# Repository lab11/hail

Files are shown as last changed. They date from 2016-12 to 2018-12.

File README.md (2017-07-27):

Hail
====

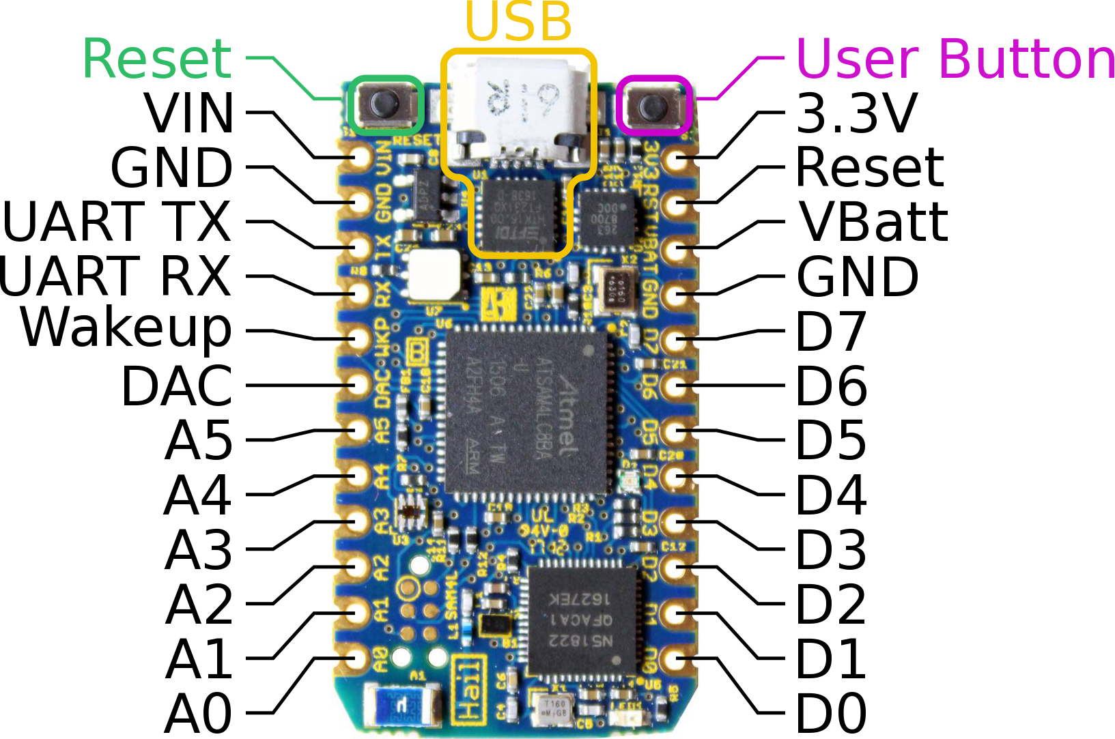
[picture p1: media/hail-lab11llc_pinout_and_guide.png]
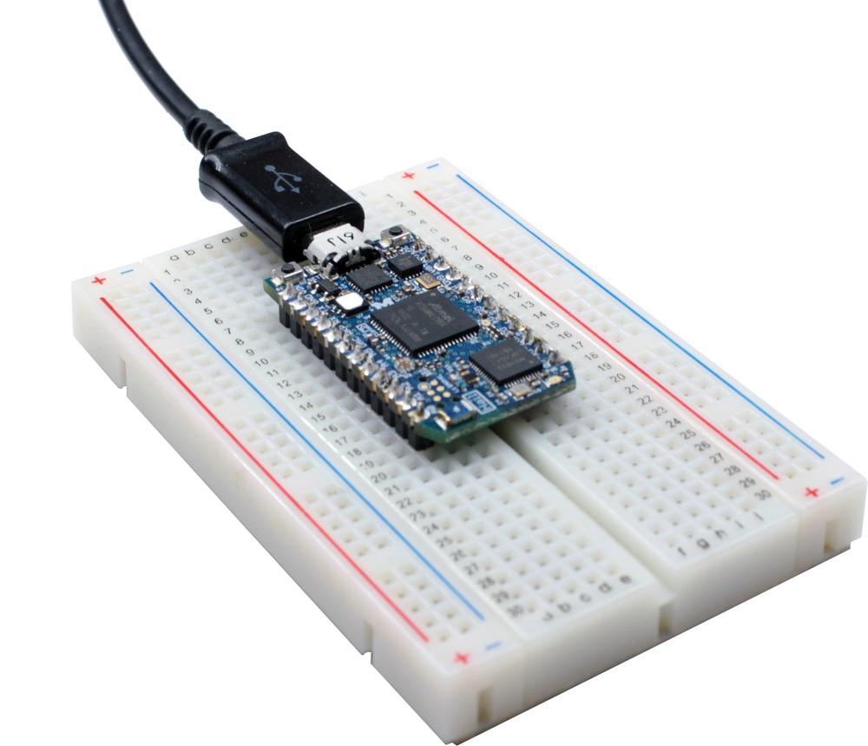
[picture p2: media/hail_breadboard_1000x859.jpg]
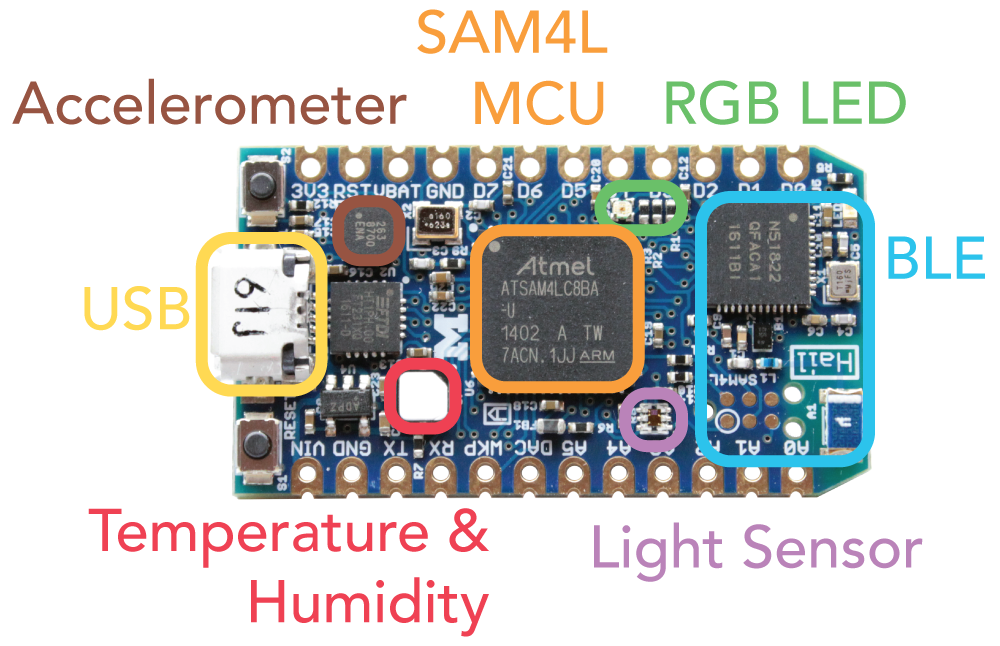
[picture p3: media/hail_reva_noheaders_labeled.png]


Hail is an IoT development module that runs the
[Tock](https://github.com/helena-project/tock) operating system.
Its features:

- [SAM4L](http://www.atmel.com/products/microcontrollers/arm/sam4l.aspx) Cortex-M4
- [nRF51822](https://www.nordicsemi.com/eng/Products/Bluetooth-low-energy/nRF51822) BLE Radio
- [SI7021](https://www.silabs.com/products/sensors/humidity-sensors/Pages/si7013-20-21.aspx) Temperature and Humidity Sensor
- [ISL29035](https://www.intersil.com/en/products/optoelectronics/ambient-light-sensors/light-to-digital-sensors/ISL29035.html) Light Sensor
- [FXOS8700CQ](http://www.nxp.com/products/sensors/6-axis-sensors/digital-sensor-3d-accelerometer-2g-4g-8g-plus-3d-magnetometer:FXOS8700CQ) 6-axis Accelerometer and Magnetometer
- RGB LED
- USB Programming
- Particle [Photon](https://www.particle.io/products/hardware/photon-wifi-dev-kit) Form-Factor and Pinout

**[Buy Now!](https://www.tockos.org/hardware/)**

Hail + Tock
-----------

[TockOS](https://github.com/helena-project/tock/tree/master/boards/hail)
supports Hail. See the instructions there for how to program the Tock kernel
and applications.

Bootloader
----------

Hail supports a software bootloader which allows new code to be flashed
over USB. The bootloader source is in the [bootloader](bootloader) directory.
The [tockloader](https://github.com/helena-project/tockloader) utility
can flash applications using the bootloader.

Commissioning New Hail Boards
-----------------------------

There a couple steps to provision a newly populated Hail board.
See the [commissioning](commissioning) folder for more information.

nRF51822 BLE Radio
------------------

By default, the nRF51822 is commissioned with the
[serialization](https://github.com/helena-project/tock-nrf-serialization)
application which allows softdevice commands to be sent over a UART connection
from the SAM4L.

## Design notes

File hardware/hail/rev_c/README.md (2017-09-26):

Hardware files
==============

Hail was created in [Eagle](http://www.autodesk.com/products/eagle/overview) and the `hail.sch` and
`hail.brd` files are Eagle schematic and board files respectively.

`hail_bom.xlsx` is the Bill of Materials (list of parts). It is also provided
as `.txt` and `.csv` files for convenience.

Rev C changes
-------------

 * Connected ADVREFP to VDDANA.
 * Replace Lab11 logo with text. In practice, it didn't print correctly.

License
-------

<a rel="license" href="http://creativecommons.org/licenses/by-sa/4.0/">
  
</a><br />
This work is licensed under a
<a rel="license" href="http://creativecommons.org/licenses/by-sa/4.0/">Creative Commons Attribution-ShareAlike 4.0 International License</a>.

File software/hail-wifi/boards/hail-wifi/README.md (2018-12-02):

The Hail with Wi-Fi Board
=================

This is the normal Hail board with the Hail-Wifi shield so it can network
over Wi-Fi.

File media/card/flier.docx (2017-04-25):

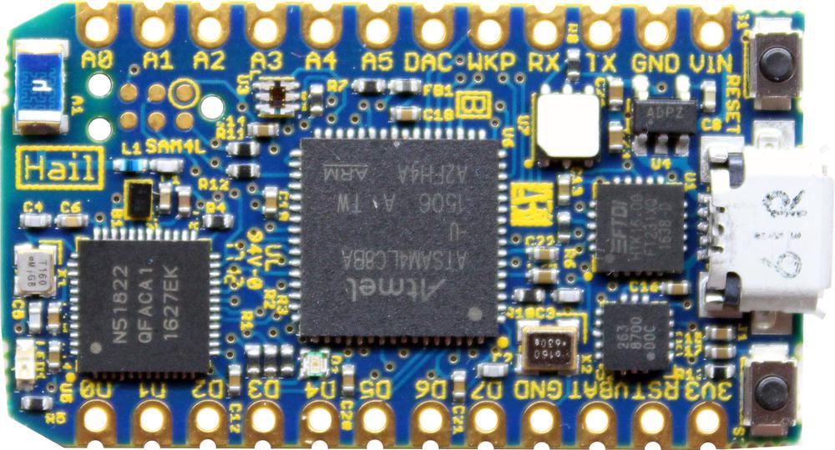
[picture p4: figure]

Hail Development Module

Hails come pre-loaded with a Tock kernel and the hail test app. To see the current readings of the sensors:

$ pip3 install tockloader
$ tockloader listen

For more detailed instructions and tutorials, please visit:

https://github.com/helena-project/tock/tree/master/boards/hail

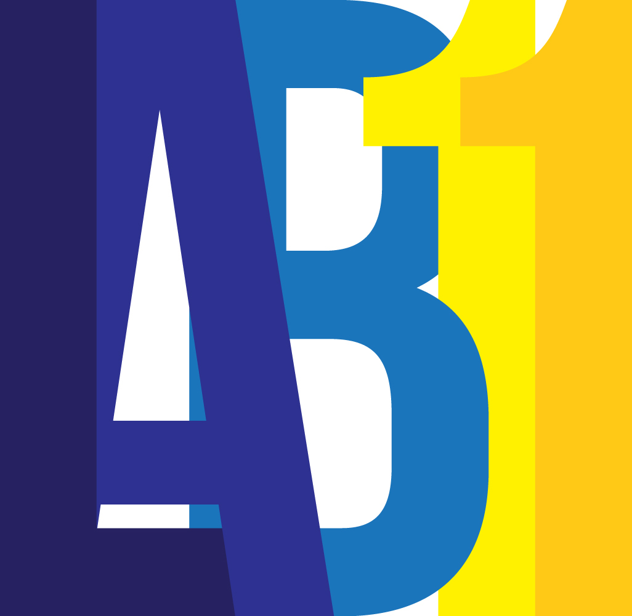
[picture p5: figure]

https://www.tockos.org/

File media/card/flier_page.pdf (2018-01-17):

# Hail Development Module

Hails come preloaded with a Tock kernel and the hail test app.

To see the current readings of the sensors, plug in Hail over USB and:

$ pip3 install tockloader

$ tockloader listen

The blue LED will also blink and pressing the user button turns on the
green LED. For more detailed instructions and tutorials, please visit:

https://www.tockos.org/hardware/hail

# Hail Development Module

Hails come preloaded with a Tock kernel and the hail test app.

To see the current readings of the sensors, plug in Hail over USB and:

$ pip3 install tockloader

$ tockloader listen

The blue LED will also blink and pressing the user button turns on the
green LED. For more detailed instructions and tutorials, please visit:

https://www.tockos.org/hardware/hail

# Hail Development Module

Hails come preloaded with a Tock kernel and the hail test app.

To see the current readings of the sensors, plug in Hail over USB and:

$ pip3 install tockloader

$ tockloader listen

The blue LED will also blink and pressing the user button turns on the
green LED. For more detailed instructions and tutorials, please visit:

https://www.tockos.org/hardware/hail

# Hail Development Module

Hails come preloaded with a Tock kernel and the hail test app.

To see the current readings of the sensors, plug in Hail over USB and:

$ pip3 install tockloader

$ tockloader listen

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

https://www.tockos.org/hardware/hail

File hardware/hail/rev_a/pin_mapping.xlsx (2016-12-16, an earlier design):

Name
Button | PA16
Blue LED | PA13
Green LED | PA14
Red LED | PA15
Particle tx | PA26
Particle rx | PA25
Particle wkp | PA07
Particle dac | PA06
Particle a5 | PB05
Particle a4 | PB04
Particle a3 | PB03
Particle a2 | PB02
Particle a1 | PA05
Particle a0 | PA04
Particle d7 | PB12
Particle d6 | PB11
Particle d5 | PA24
Particle d4 | PA23
Particle d3 | PA21
Particle d2 | PA22
Particle d1 | PB15
Particle d0 | PB14
NRF_IN | PB10
NRF_OUT | PB09
NRF_RTS | PB06
NRF_CTS | PB07
NRF_INT | PB08
NRF_RESET | PA17
Sensors SDA | PB00
Sensors SCL | PB01
Light INT | PA20
ACC INT1 | PA09
ACC INT2 | PA18
FTDI_OUT | PA11
FTDI_IN | PA12
FTDI_RTS | PA08
36

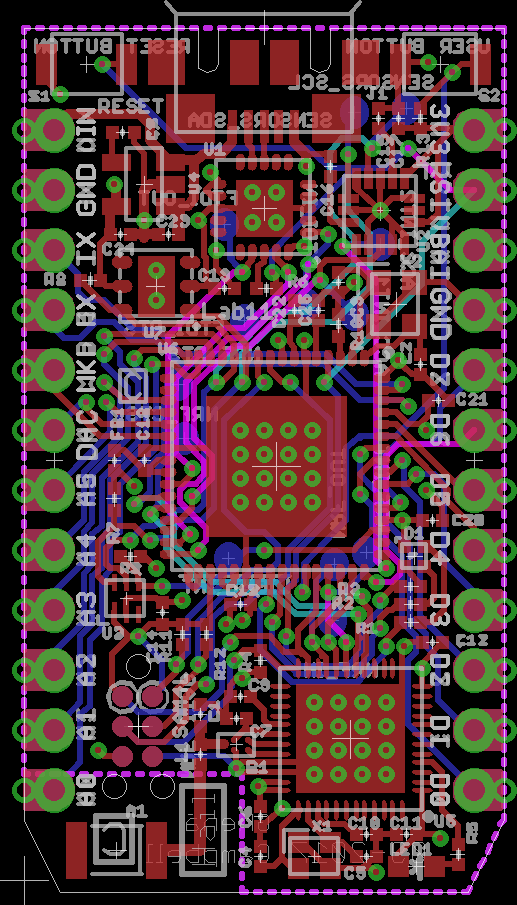
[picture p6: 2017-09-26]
hardware/hail/rev_c/hail_pcb.png

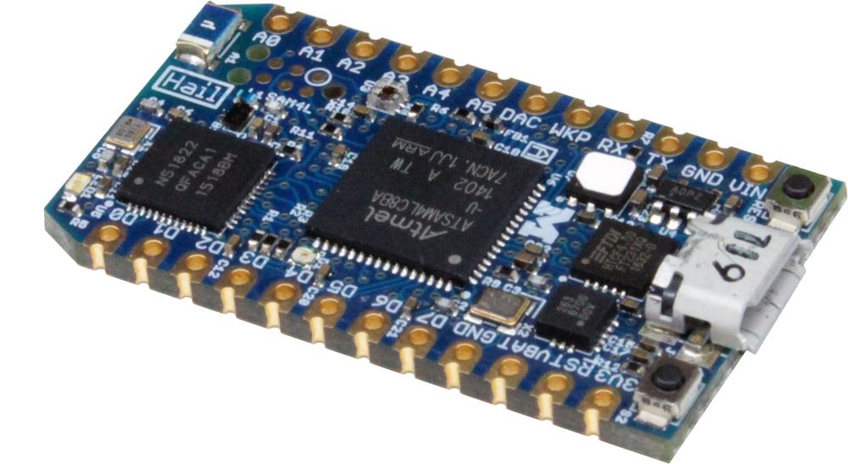
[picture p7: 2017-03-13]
media/hail_reva_isometric_1000x547.jpg

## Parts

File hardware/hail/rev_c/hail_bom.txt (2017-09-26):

# Bill of Materials
# Converted from hail_bom.xlsx
# Generated by bom_to_text.py
#
# # Bill of Materials                                                                                                                                                                                                                                                                                                      
# # Converted from {}                                                                                                                                                                                                                                                                                                      
# # Generated by bom_to_text.py                                                                                                                                                                                                                                                                                            
# #                                                                                                                                                                                                                                                                                                                        
#                                                                                                                                                                                                                                                                                                                          
# Qty                            Value                           Device                          Package                          Parts                                                            Description                                                     MPN              DIGIKEY               MOUSER           RICHARDSON_RFPD
1                                FRACTUS-2.4GHZ-FR05-S1-N-0-110  FRACTUS-2.4GHZ-FR05-S1-N-0-110  FRACTUS-ANTENNA-FR05-S1-N-0-110  A1                                                               Fractus Micro Reach Xtend                                                                                               FR05-S1-N-0110B
1                                BAL-NRF01D3                     BAL-NRF01D3                     BAL-NRF01D3                      B1                                                               50 ohm nominal input / conjugate match balun to nRF51422-QFAA,                   497-13637-1-ND        511-BAL-NRF01D3  
1                                1.5pF                           CAPACITOR0402_CAP               0402_CAP                         C1                                                               0402 Capacitor                                                                   490-6212-1-ND                          
2                                8pF                             CAPACITOR0402_CAP               0402_CAP                         C2, C3                                                           0402 Capacitor                                                                   490-8230-1-ND                          
2                                12pF                            CAPACITOR0402_CAP               0402_CAP                         C4, C5                                                           0402 Capacitor                                                                   490-6197-1-ND                          
1                                1nF                             CAPACITOR0402_CAP               0402_CAP                         C6                                                               0402 Capacitor                                                                   490-1303-1-ND                          
1                                2.2nF                           CAPACITOR0402_CAP               0402_CAP                         C7                                                               0402 Capacitor                                                                   490-5419-1-ND                          
1                                10nF                            CAPACITOR0402_CAP               0402_CAP                         C8                                                               0402 Capacitor                                                                   490-7763-1-ND                          
1                                47nF                            CAPACITOR0402_CAP               0402_CAP                         C9                                                               0402 Capacitor                                                                   445-1264-1-ND                          
13                               100nF                           CAPACITOR0402_CAP               0402_CAP                         C10, C11, C12, C13, C14, C15, C16, C17, C18, C19, C20, C21, C22  0402 Capacitor                                                                   490-10777-1-ND                         
3                                4.7uF                           CAPACITOR0402_CAP               0402_CAP                         C23, C24, C25                                                    0402 Capacitor                                                                   490-13252-1-ND                         
1                                SML-LX0404SIUPGUSB              SML-LX0404SIUPGUSB              1MM_SQ_4PAD                      D1                                                               1mm^2 RGB LED                                                                    67-2125-1-ND                           
1                                1.5k                            FERRITE_BEAD0402                0402_CAP                         FB1                                                                                                                                               1276-6395-1-ND                         
1                                MICRO_USB_B_HIROSE_ZX62R-B-5P   MICRO_USB_B_HIROSE_ZX62R-B-5P   USB_MICRO_B-HIROSE-ZX62R-B-5P    J1                                                               USB Micro B Connector                                                            H125274CT-ND                           
1                                M12PTH-CST-L                    M12PTH-CST-L                    1X12-CASTELLATED                 J2                                                               Header 12                                                                        S1011E-12-ND                           
1                                M12PTH-CST-R                    M12PTH-CST-R                    1X12-CASTELLATED                 J3                                                               Header 12                                                                        S1011E-12-ND                           
1                                6.8nH                           INDUCTOR0402                    0402_CAP                         L1                                                               A very specific inductor                                                         490-6840-1-ND                          
1                                LED0603                         LED0603                         LED-0603                         LED1                                                             LED                                                                              160-1837-6-ND                          
6                                1k                              RESISTOR0402_RES                0402_RES                         R1, R2, R3, R4, R5, R6                                           Resistor                                                                         1276-3430-1-ND                         
4                                10k                             RESISTOR0402_RES                0402_RES                         R7, R8, R9, R10                                                  Resistor                                                                         1276-3431-1-ND                         
3                                100k                            RESISTOR0402_RES                0402_RES                         R11, R12, R13                                                    Resistor                                                                         1276-3432-1-ND                         
2                                B3U-1000P                       B3U-1000P                       B3U-1000P                        S1, S2                                                           Switch                                                                           SW1020CT-ND                            
1                                FT231XQ                         FT231XQ                         QFN-20-4MM                       U1                                                               USB Bridge, USB to UART USB 2.0 UART Interface                  FT231XQ-R        768-1128-1-ND                          
1                                FXOS8700CQ                      FXOS8700CQ                      QFN-16-3MM                       U2                                                               Accelerometer, Magnetometer, 3 Axis Sensor, I2C/SPI             FXOS8700CQR1     FXOS8700CQR1CT-ND                      
1                                ISL29035                        ISL29035                        ODFN-6-1.5MMX1.6MM               U3                                                               Optical Sensor Ambient 550nm I2C                                ISL29035IROZ-T7  ISL29035IROZ-T7CT-ND                   
1                                MAX8887EZK33+T                  MAX8887EZK33+T                  SOT-23-5                         U4                                                               IC REG LDO 3.3V 0.3A TSOT23-5                                                    MAX8887EZK33+TCT-ND                    
1                                NRF51822QF                      NRF51822QF                      QFN-48-6MM                       U5                                                               Multiprotocol Bluetooth 4.0 low energy/2.4 GHz RF SoC                            1490-1049-1-ND                         
1                                SAM4LC8BA                       SAM4LC8BA                       QFN-64-9MM                       U6                                                               SAM4L Microcontroller. 64QFN Package. 512 Flash.                                 ATSAM4LC8BA-MURCT-ND                   
1                                SI7021                          SI7021                          DFN-6/3MM                        U7                                                               IC TEMP SENSOR RH 2% DFN                                                         336-3141-ND                            
1                                16MHz                           TXC-8Y                          TXC-8Y                           X1                                                               2mmx1.6mm SMD Crystal                                                            887-2003-1-ND                          
1                                16MHz                           FH1600015                       FHXXX                            X2                                                               Pericom Type FH 16 MHz 2.5 x 2.0 mm                                              FH1600015CT-ND

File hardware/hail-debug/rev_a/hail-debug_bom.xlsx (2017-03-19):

Qty | Value | Device | Package | Parts | Description | DIGIKEY | MOUSER | NEWARK
24 | MILLMAX_0908-X-15-20-75-14-11-0 | MILLMAX_0908-X-15-20-75-14-11-0 | POGO_0908-X-15-20-75-14-11-0 | J1, J2, J3, J4, J5, J6, J7, J8, J9, J10, J11, J12, J13, J14, J15, J16, J17, J18, J19, J20, J21, J22, J23, J24 |  | ED90384-ND
19 | MILLMAX_0985-X-15-20-71-14-11-0 | MILLMAX_0985-X-15-20-71-14-11-0 | POGO_0985-X-15-20-71-14-11-0 | J25, J26, J27, J28, J29, J30, J31, J32, J33, J34, J35, J36, J37, J38, J39, J40, J41, J42, J43 |  | ED1122-ND
2 |  | PINHD-2X12 | 2X12 | J44, J45 | PIN HEADER | S2011EC-12-ND
1 |  | PINHD-2X14 | 2X14 | J46 | PIN HEADER | S2011EC-14-ND
2 | SCREW-TERMINAL_7_0.100 | SCREW-TERMINAL_7_0.100 | CONN_BLOCK_7 | J47, J48 | 7x 0.100 in screw terminal block | 277-1278-ND | 651-1725708 | 14X4980
2 | SCREW_TERMINAL_12_0.100 | SCREW_TERMINAL_12_0.100 | CONN_BLOCK_12 | J49, J50 |  | 277-1283-ND
1 | PTS645SM43SMTR92 | PTS645SM43SMTR92 | PTS645 | S1 | Tactile Switch SPST-NO Top Actuated Surface Mount | CKN9112CT-ND

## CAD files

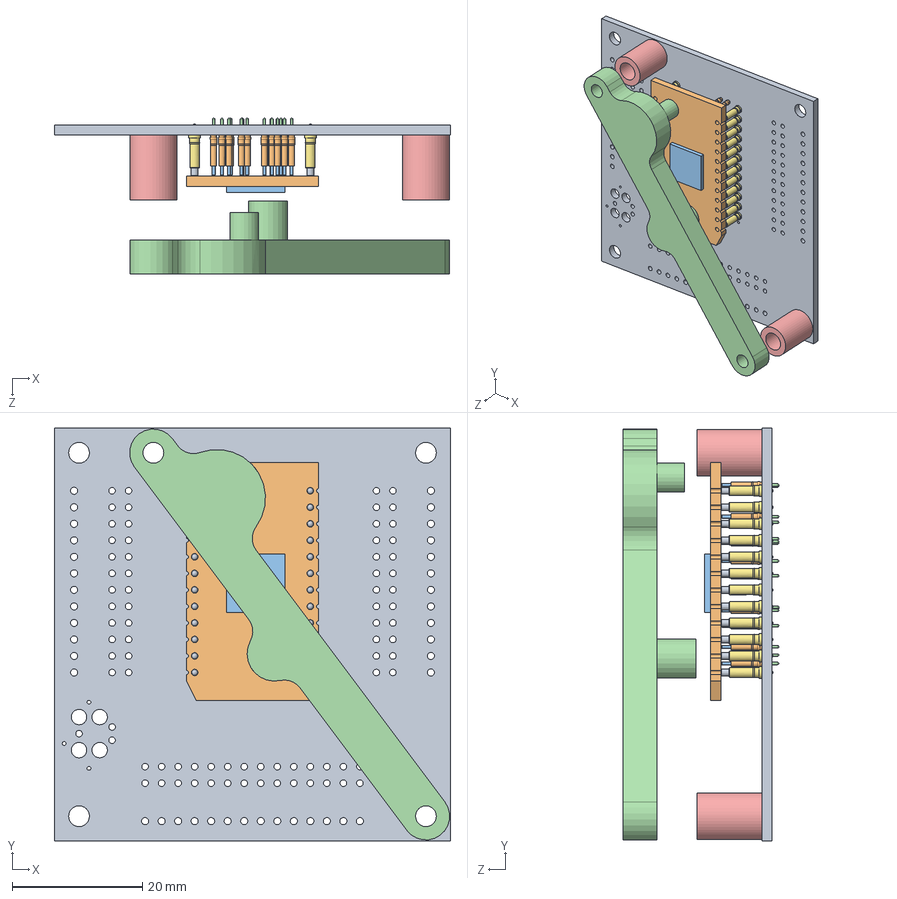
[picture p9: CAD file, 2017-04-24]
3d/hail-debug/hail-debug.SLDASM
61.0 x 63.5 x 23.9 mm
haildebug
mill-max-0985-0-15-20-71-14-11-0_9350-0 x 19
mill-max-0985-0-15-20-71-14-11-0_9315-0 x 19
mill-max-0985-0-15-20-71-14-11-0_9385-X x 19
mill-max-0985-0-15-20-71-14-11-0_SPRING x 19
mill-max-0908-0-15-20-75-14-11-0_0963-0 x 24
mill-max-0908-0-15-20-75-14-11-0_0954-0 x 24
mill-max-0908-0-15-20-75-14-11-0_SPRING x 24
mill-max-0908-0-15-20-75-14-11-0_0918-X x 24
hail
sam4l
holder_bracket_long
holder_bracket_post x 2

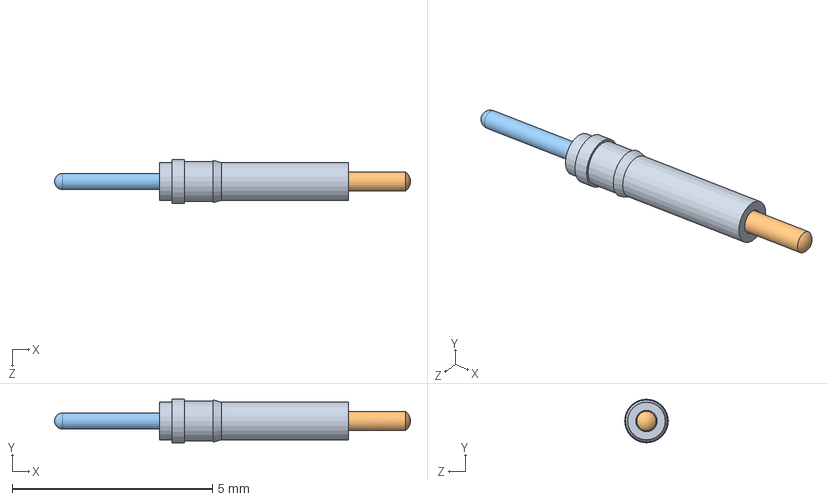
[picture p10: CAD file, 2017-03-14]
3d/mill-max-0985-0-15-20-71-14-11-0/mill-max-0985-0-15-20-71-14-11-0.sldasm
8.89 x 1.09 x 1.09 mm
mill-max-0985-0-15-20-71-14-11-0_9350-0
mill-max-0985-0-15-20-71-14-11-0_9315-0
mill-max-0985-0-15-20-71-14-11-0_9385-X
mill-max-0985-0-15-20-71-14-11-0_SPRING

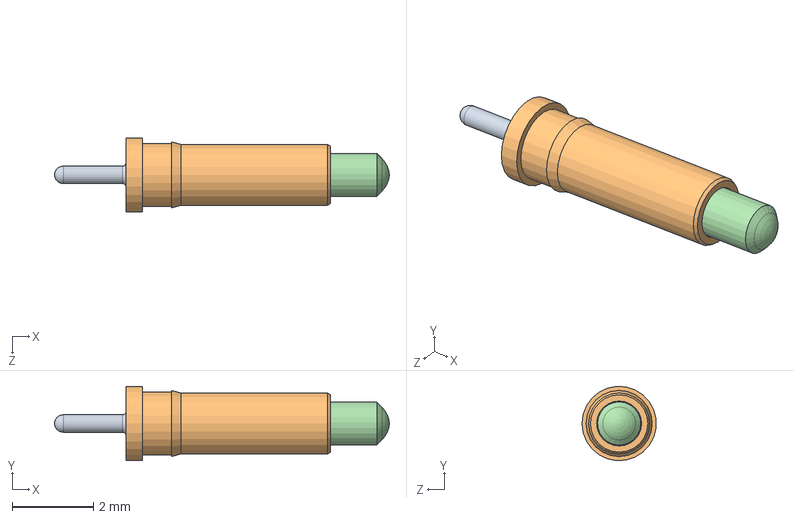
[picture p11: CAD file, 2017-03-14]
3d/mill-max-0908-0-15-20-75-14-11-0/mill-max-0908-0-15-20-75-14-11-0.sldasm
8.23 x 1.83 x 1.82 mm
mill-max-0908-0-15-20-75-14-11-0_0963-0
mill-max-0908-0-15-20-75-14-11-0_0954-0
mill-max-0908-0-15-20-75-14-11-0_SPRING
mill-max-0908-0-15-20-75-14-11-0_0918-X

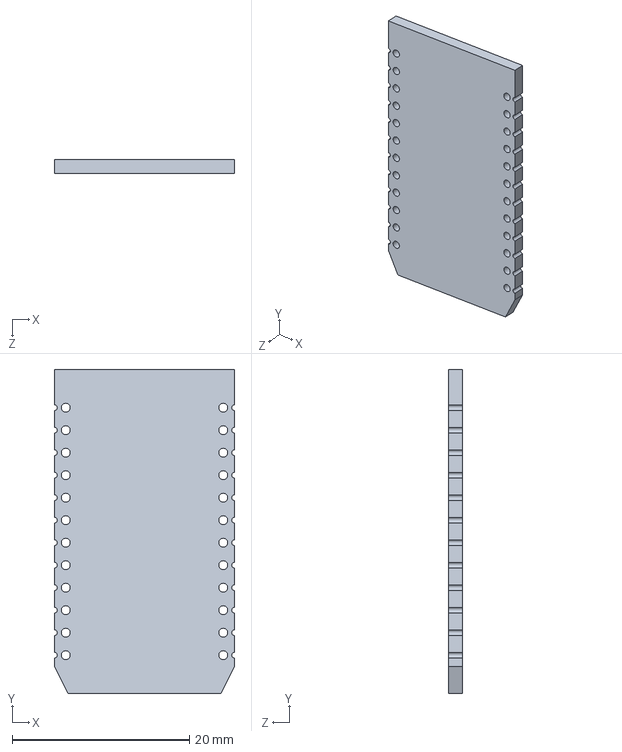
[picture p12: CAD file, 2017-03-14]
3d/hail-debug/hail.SLDASM
20.3 x 36.6 x 1.58 mm

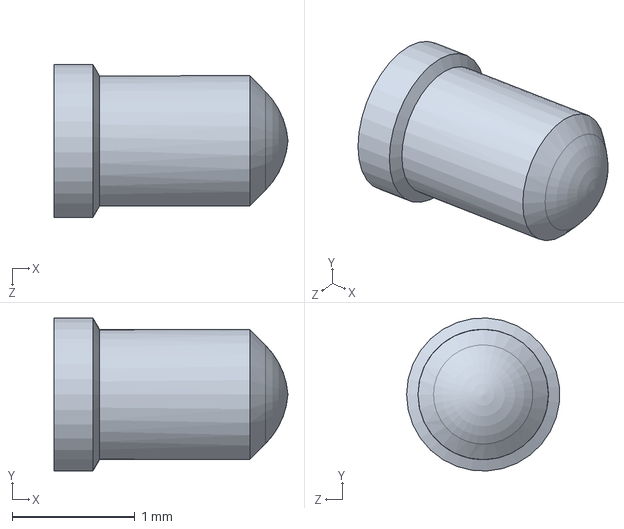
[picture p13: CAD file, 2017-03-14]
3d/mill-max-0908-0-15-20-75-14-11-0/mill-max-0908-0-15-20-75-14-11-0_0918-X.sldprt
1.90 x 1.25 x 1.24 mm

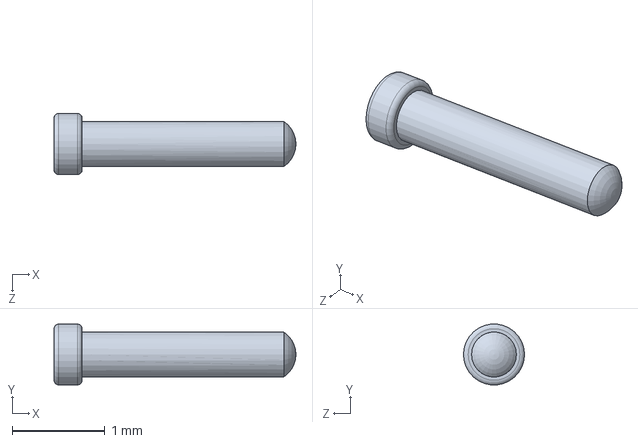
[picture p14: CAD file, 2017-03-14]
3d/mill-max-0985-0-15-20-71-14-11-0/mill-max-0985-0-15-20-71-14-11-0_9315-0.sldprt
2.62 x 0.657 x 0.66 mm

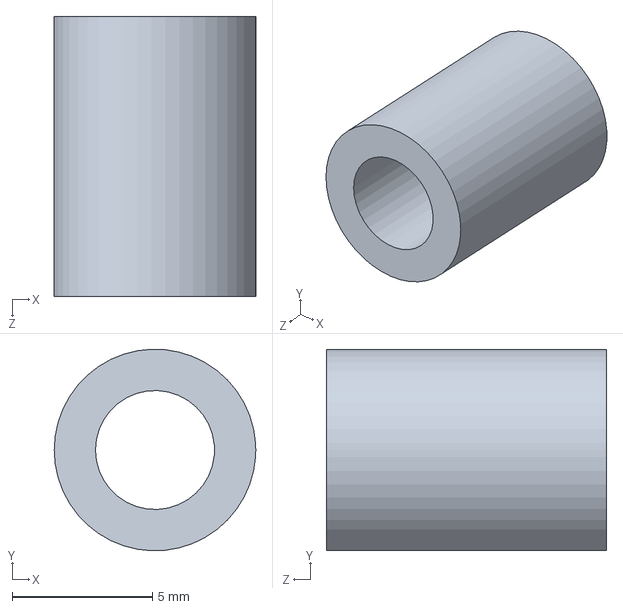
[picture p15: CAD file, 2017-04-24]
3d/hail-debug/holder_bracket_post.SLDPRT
7.20 x 7.20 x 10.0 mm

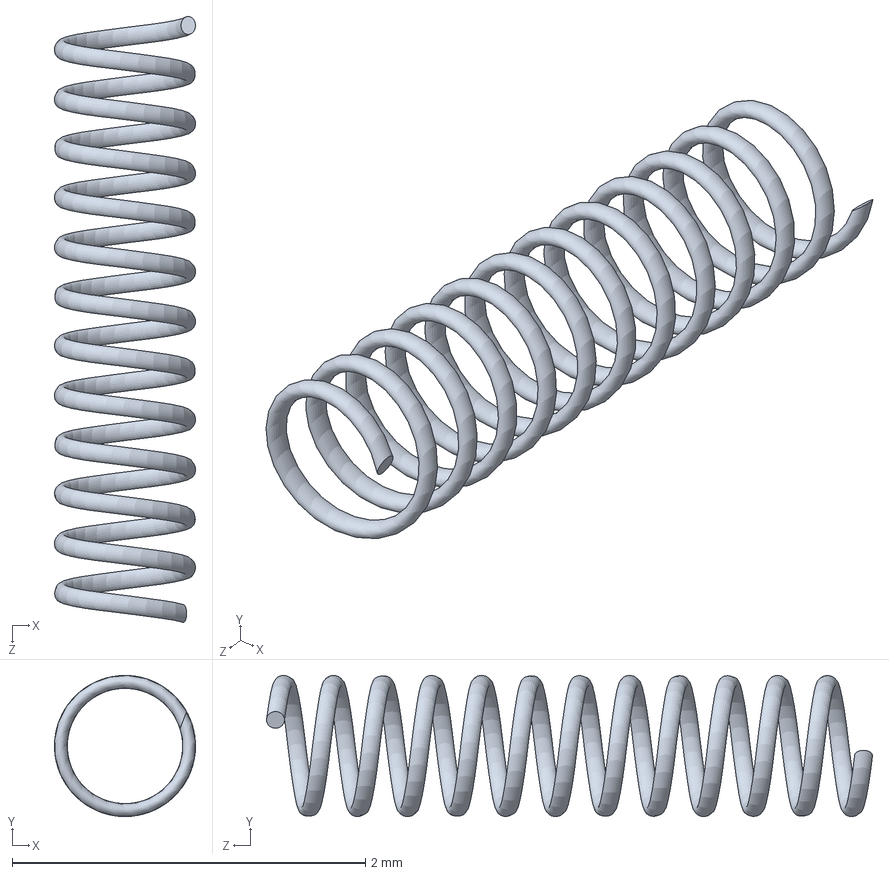
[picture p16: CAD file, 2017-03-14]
3d/mill-max-0908-0-15-20-75-14-11-0/mill-max-0908-0-15-20-75-14-11-0_SPRING.sldprt
0.799 x 0.799 x 3.43 mm

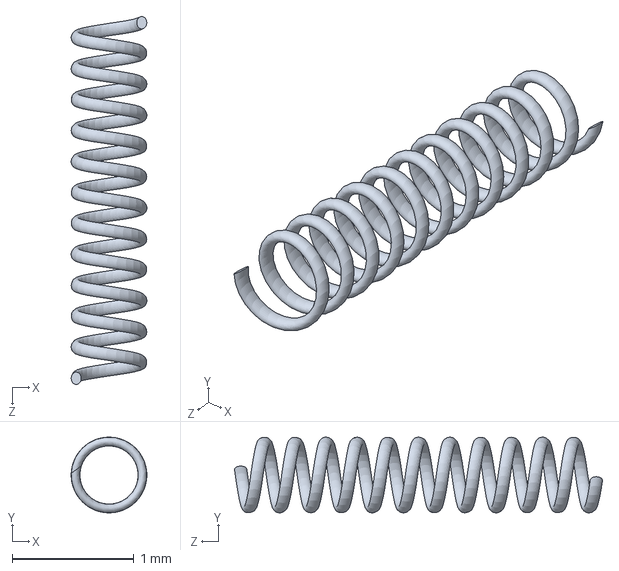
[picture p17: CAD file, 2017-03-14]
3d/mill-max-0985-0-15-20-71-14-11-0/mill-max-0985-0-15-20-71-14-11-0_SPRING.sldprt
0.622 x 0.622 x 3.02 mm

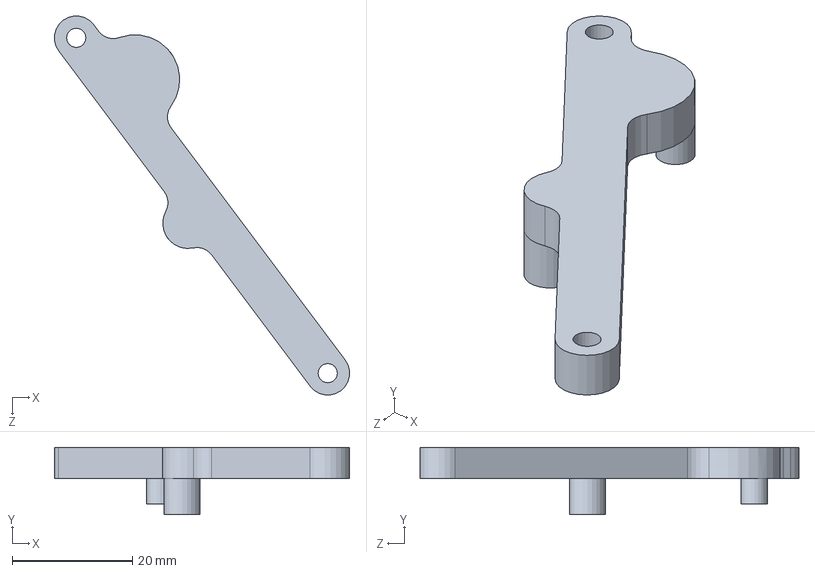
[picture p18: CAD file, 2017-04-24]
3d/hail-debug/holder_bracket_long.SLDPRT
49.2 x 11.2 x 63.1 mm

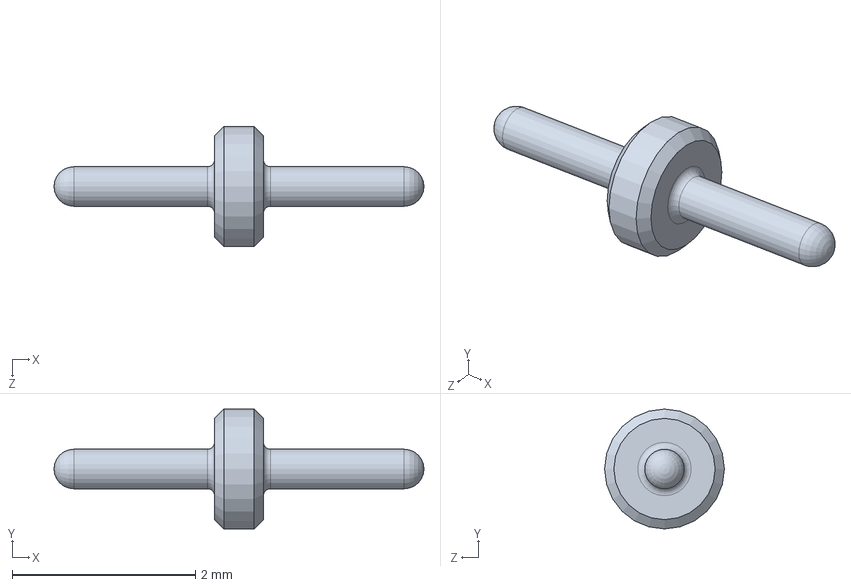
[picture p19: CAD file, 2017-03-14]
3d/mill-max-0908-0-15-20-75-14-11-0/mill-max-0908-0-15-20-75-14-11-0_0963-0.sldprt
4.04 x 1.31 x 1.31 mm

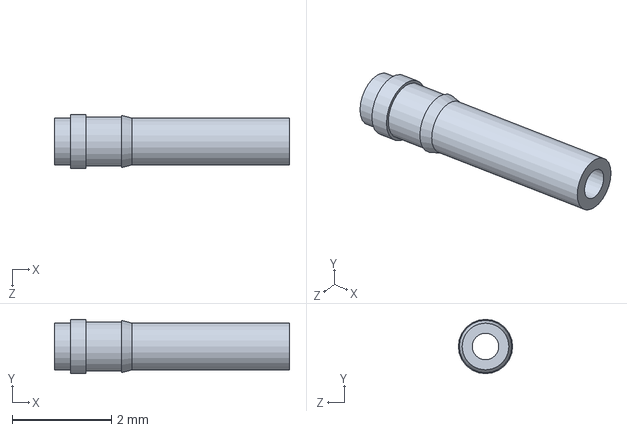
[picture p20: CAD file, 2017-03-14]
3d/mill-max-0985-0-15-20-71-14-11-0/mill-max-0985-0-15-20-71-14-11-0_9350-0.sldprt
4.72 x 1.09 x 1.09 mm

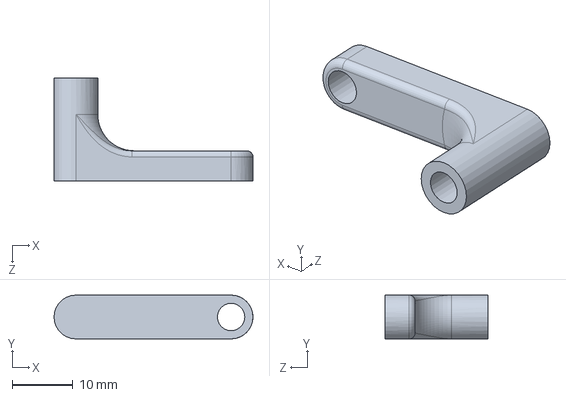
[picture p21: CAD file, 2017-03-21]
3d/hail-debug/holder_bracket.SLDPRT
32.7 x 7.20 x 17.0 mm

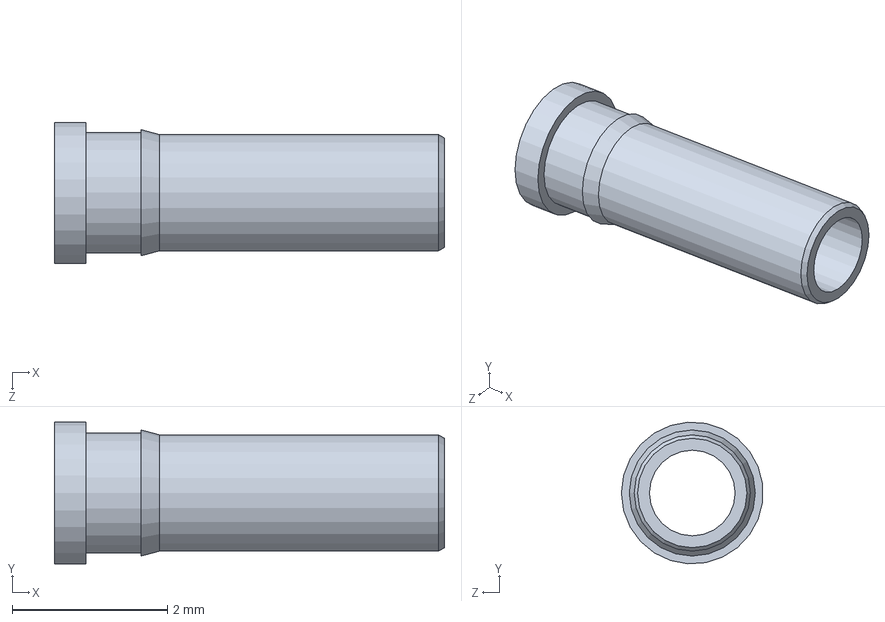
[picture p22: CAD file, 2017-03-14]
3d/mill-max-0908-0-15-20-75-14-11-0/mill-max-0908-0-15-20-75-14-11-0_0954-0.sldprt
5.03 x 1.83 x 1.82 mm

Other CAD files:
3d/hail-debug/sam4l.SLDPRT
3d/mill-max-0985-0-15-20-71-14-11-0/mill-max-0985-0-15-20-71-14-11-0_9385-X.sldprt

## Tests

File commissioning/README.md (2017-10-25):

Commissioning
=============

This folder contains resources for setting up new Hail boards.

Commissioning Overview
----------------------

The commissioning process covers a few things:

1. Set the FTDI device name and serial number.
2. Flashes the boatloader on to the SAM4L.
3. Sets the `board` and `id` attributes in the flash of the SAM4L.
4. Flashes the `hail` TockOS kernel on the SAM4L.
5. Flashes the "hail" app on the SAM4L.
6. Flashes the serialization code on the nRF51822 and programs the ID.

Initial software installation
-----------------------------

### Pre-Requisites:

  - You need the `libftdi-dev` package (or equivalent).
  - [JLinkExe](https://www.segger.com/downloads/jlink#J-LinkSoftwareAndDocumentationPack)

-------------

To initialize a Hail board:

 * Connect USB to the board
 * Connect a JTAG programmer to the SAM4L
 * Run `./commission_new_hail.sh c098e513XXXX` where the `XXXX` should be
   replaced with a unique device ID
 * Connect a JTAG programmer to the nRF51822
 * Hit `any key` to continue the script

Be sure to label the board with a sticker so that the user knows what the
device's BLE address is.

`ftx_prog`
----------

The `ftx_prog` executable comes from here:
https://github.com/richardeoin/ftx-prog.
It was built for linux amd64, so if the executable doesn't work for you,
you will have to recompile it for your platform.

Testing
-------

1. Connect Hail to USB
2. Run `tockloader listen` and verify that code is running
3. Press the reset button and verify that code restarts
4. Press the User button and verify that the green led activates
5. Hold the Hail in your hand and verify that the light and acceleration measurements change
6. Verify that BLE is transmitting with the name of `Hail` and that the address matches the sticker

For BLE testing, I recommend running
`sudo stdbuf -oL hcitool lescan --duplicates | grep Hail` in the background.

Troubleshooting
---------------

### Permissions

    ftdi_usb_open() failed for 0403:6015: inappropriate permissions on device!

You need to add a udev rule for FTDI devices:

    sudo cp udev/99-ftdi.rules /etc/udev/rules.d/

Then unplug and replug attached FTDI devices.

### Device not found

    ftdi_usb_open() failed for 0403:6015: device not found

This seems to occasionally happen. Just run the script again.

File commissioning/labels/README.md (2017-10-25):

Hail Labels
===========

To generate labels:

    ./labels.py [michgan|lab11llc] <id> <count>

For example:

    ./labels.py michigan 005c 100

To make 100 labels with the block "M" on them starting at address
`C0:98:E5:13:00:5C`.

Warning
-------

You may have to manually install `svgutils` in order to get everything working.
Their pip package is way out of date. [Go here](https://github.com/btel/svg_utils).

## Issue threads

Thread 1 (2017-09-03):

ADVREFP needs to be tied to VDDANA

brghena, 2017-09-03:
ADVREFP should be connected to VDDANA. This can be done on existing boards with a small solder jumper (and has been done for boards shipped to macrofab). We should fix this for future revisions though. Mentioning as an issue so we don't forget about it.

Closed 2017-09-26.

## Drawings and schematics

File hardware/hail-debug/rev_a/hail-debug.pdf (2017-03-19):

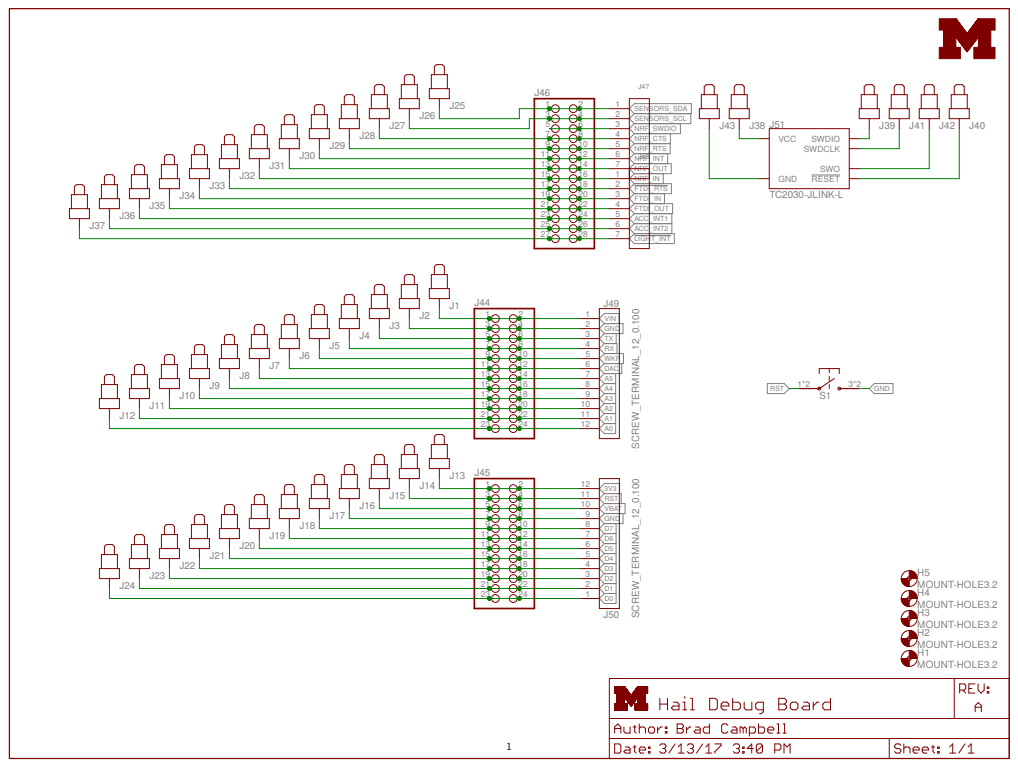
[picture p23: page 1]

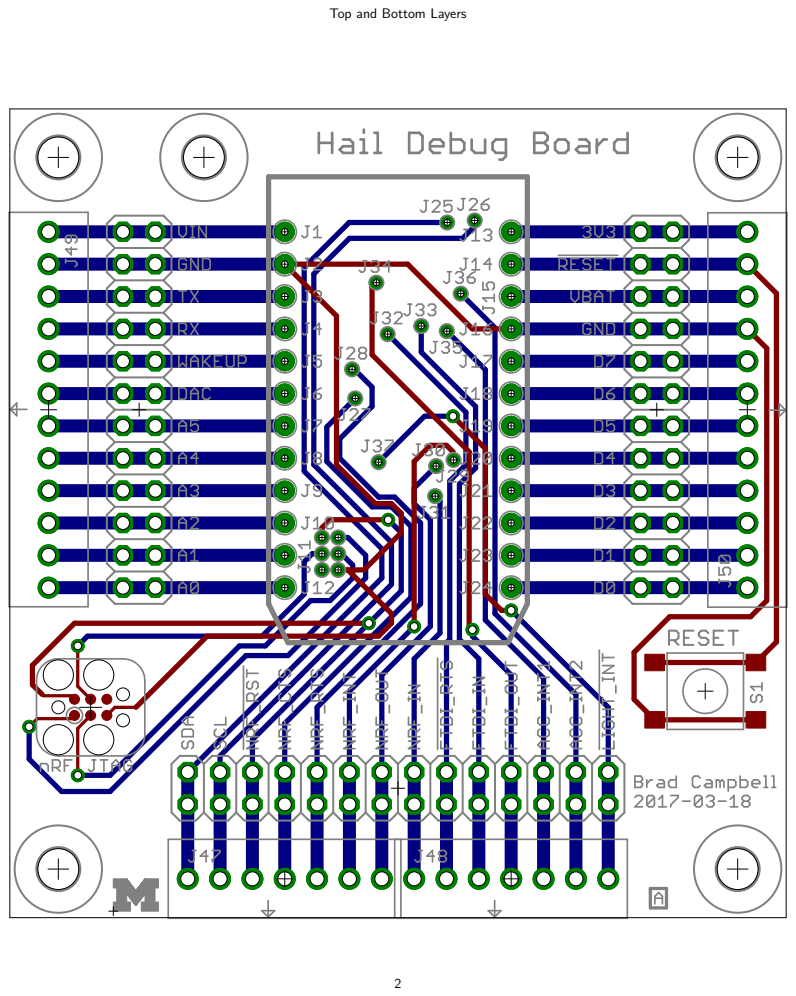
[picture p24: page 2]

Top and Bottom Layers

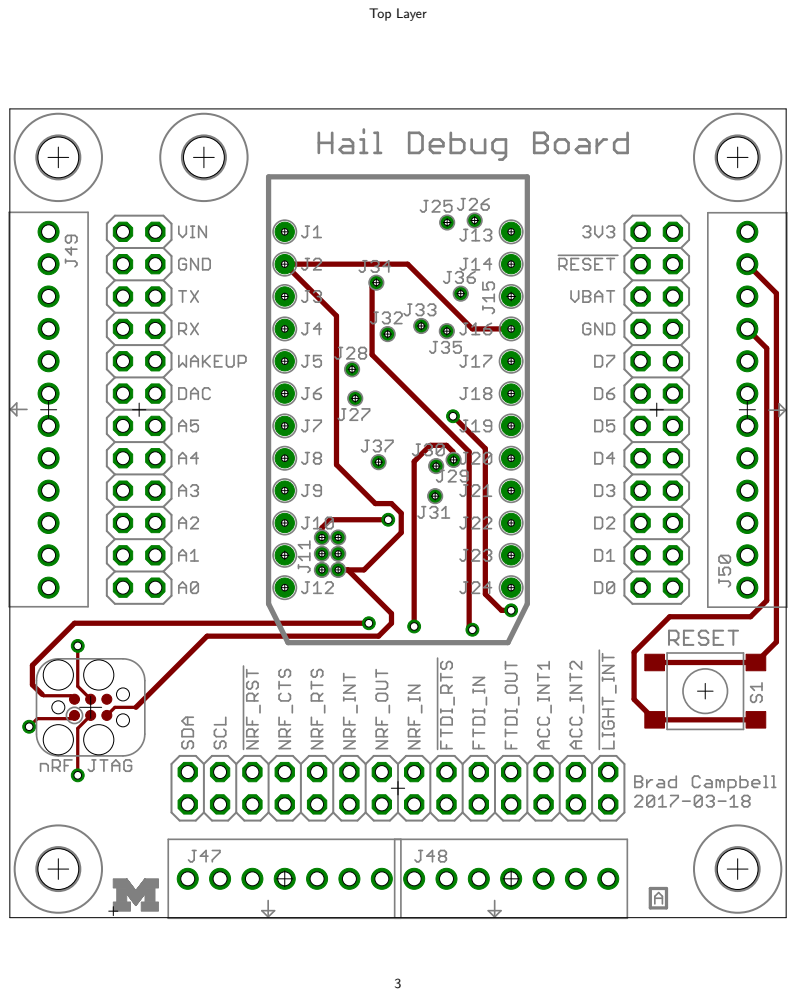
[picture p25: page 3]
Top Layer

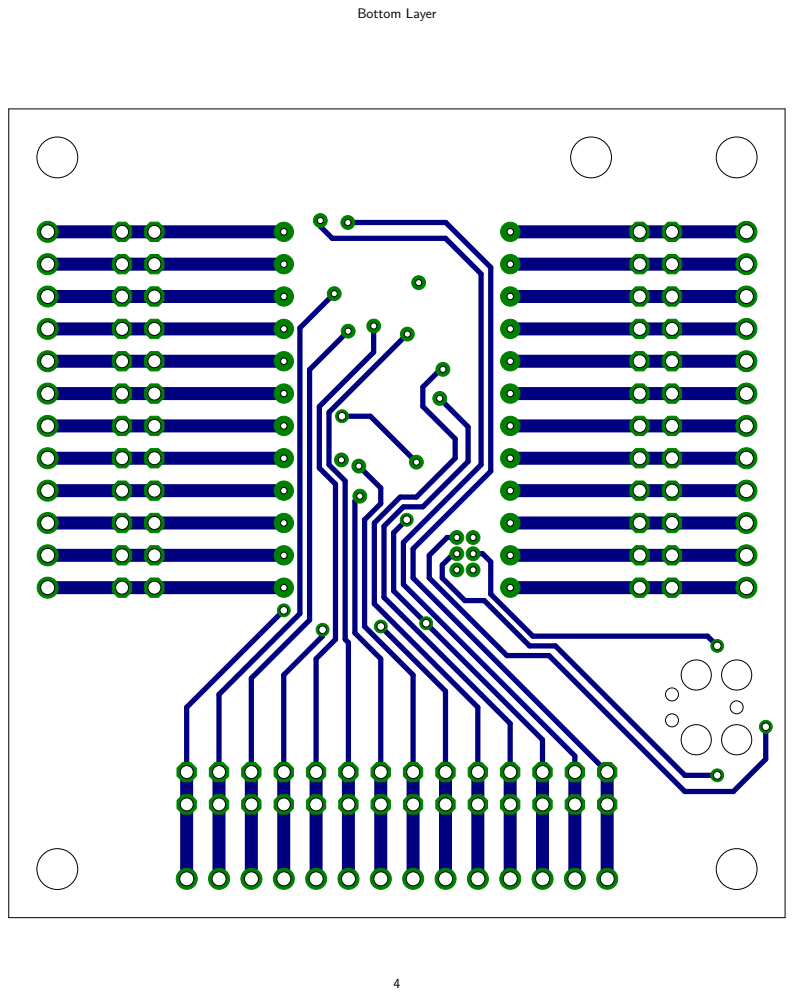
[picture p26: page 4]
Bottom Layer

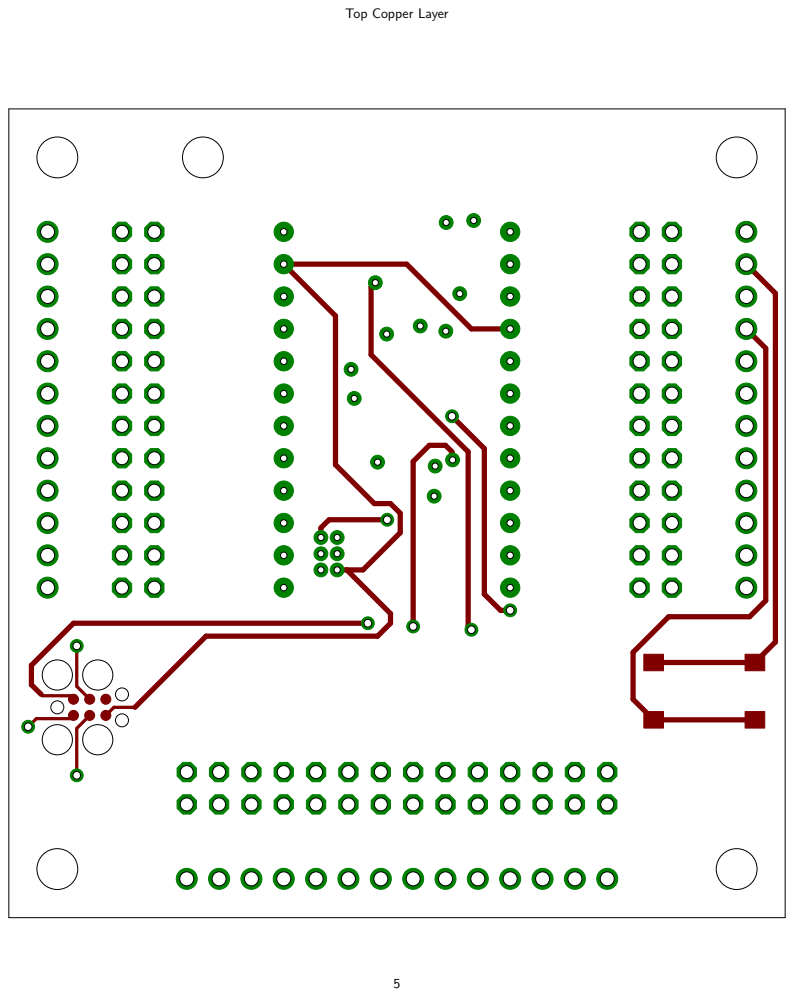
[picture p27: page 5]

Top Copper Layer

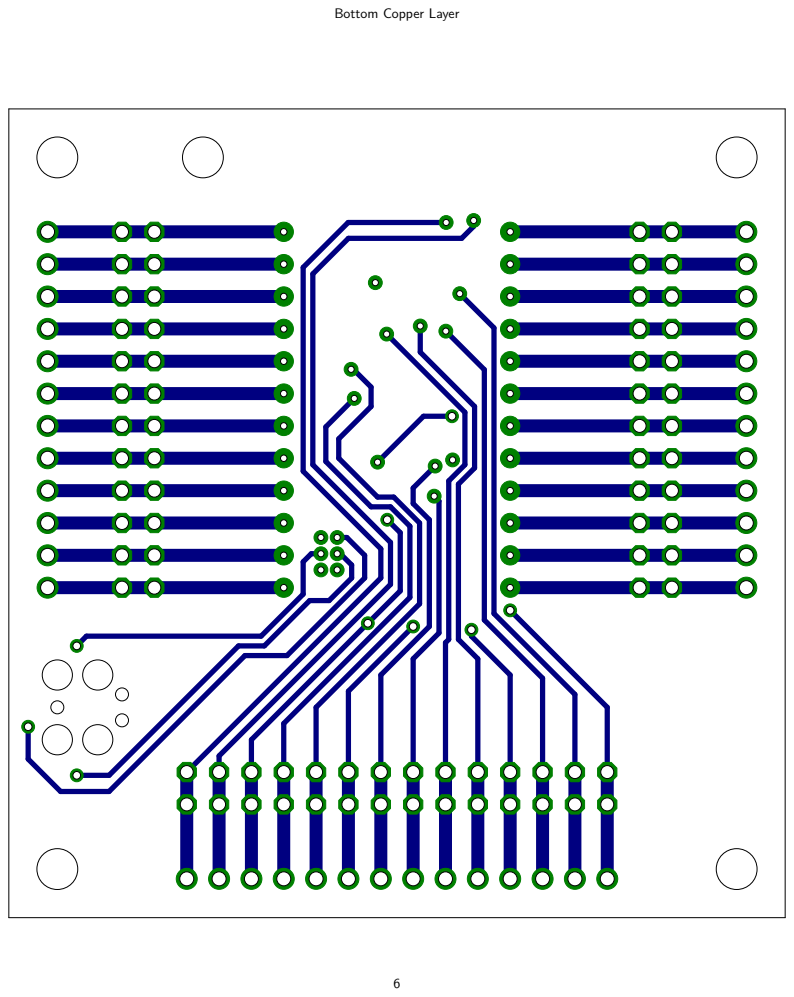
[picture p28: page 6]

Bottom Copper Layer

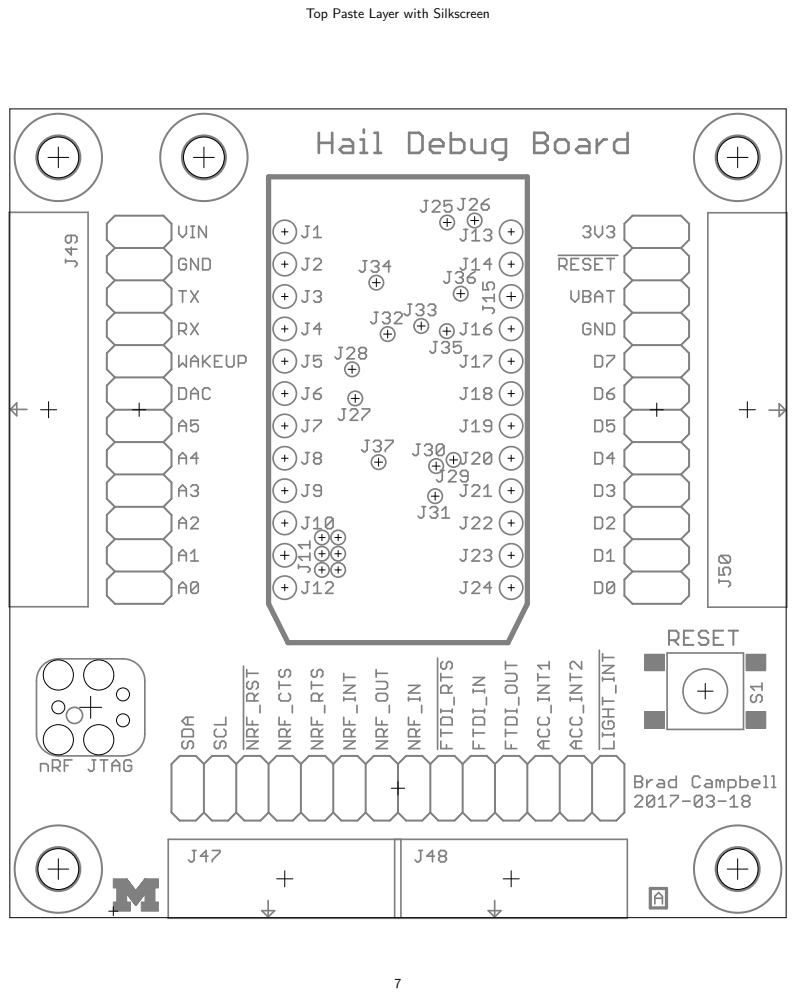
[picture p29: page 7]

Top Paste Layer with Silkscreen

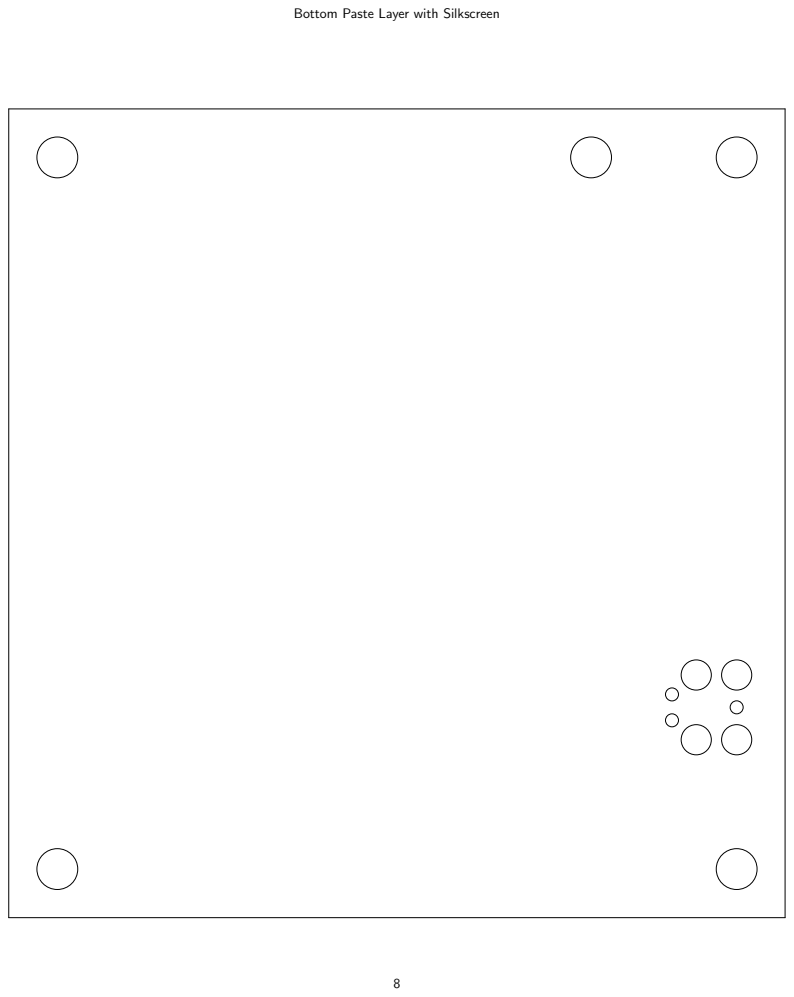
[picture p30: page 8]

Bottom Paste Layer with Silkscreen

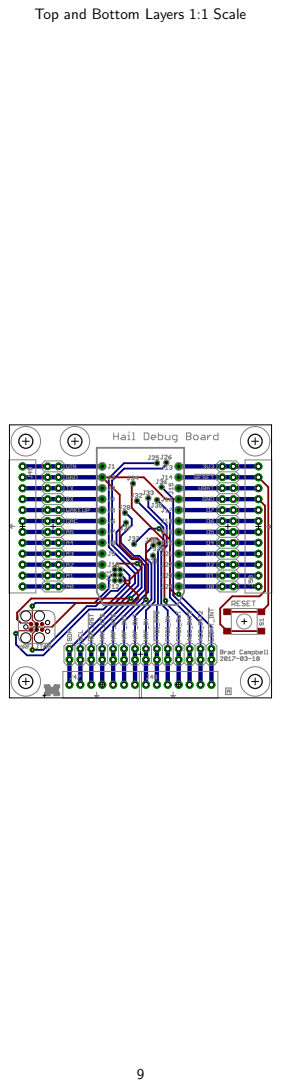
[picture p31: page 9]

Top and Bottom Layers 1:1 Scale

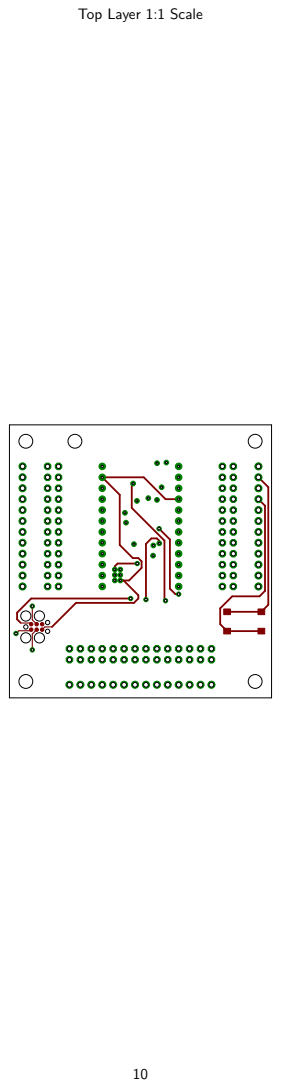
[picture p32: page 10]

Top Layer 1:1 Scale

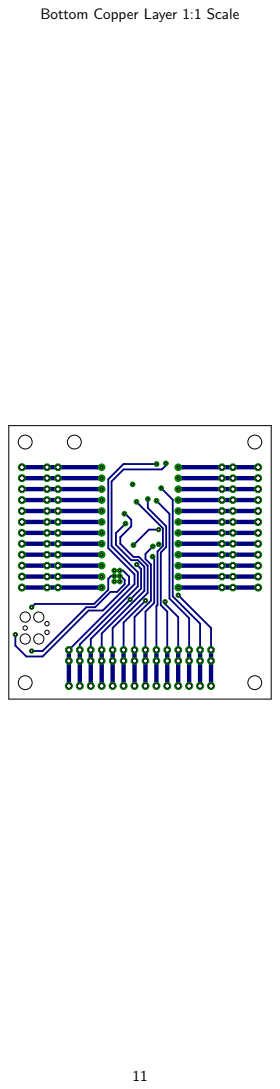
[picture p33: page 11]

Bottom Copper Layer 1:1 Scale

Qty Value | Device
24 MILLMAX_0908-X-15-20-75-14-11-0 | MILLMAX_0908-X-15-20-75-14-11-0
19 MILLMAX_0985-X-15-20-71-14-11-0 | MILLMAX_0985-X-15-20-71-14-11-0
2 | PINHD-2X12
1 | PINHD-2X14
2 SCREW-TERMINAL_7_0.100 | SCREW-TERMINAL_7_0.100
2 SCREW_TERMINAL_12_0.100 | SCREW_TERMINAL_12_0.100
1 PTS645SM43SMTR92 | PTS645SM43SMTR92

Package
POGO_0908-X-15-20-75-14-11-0 POGO_0985-X-15-20-71-14-11-0 2X12
2X14
CONN_BLOCK_7
CONN_BLOCK_12
PTS645

Parts
J1, J2, J3, J4, J5, J6, J7, J8, J9, J10, J11, J12, J13, J14, J15, J16, J17, J18, J19, J20, J21, J22, J23, J24 J25, J26, J27, J28, J29, J30, J31, J32, J33, J34, J35, J36, J37, J38, J39, J40, J41, J42, J43
J44, J45
J46
J47, J48
J49, J50
S1

Description | DIGIKEY | MOUSER | NEWARK
| ED90384-ND
| ED1122-ND
PIN HEADER | S2011EC-12-ND
PIN HEADER | S2011EC-14-ND
7x 0.100 in screw terminal block | 277-1278-ND | 651-1725708 14X4980
| 277-1283-ND
Tactile Switch SPST-NO Top Actuated Surface Mount | CKN9112CT-ND

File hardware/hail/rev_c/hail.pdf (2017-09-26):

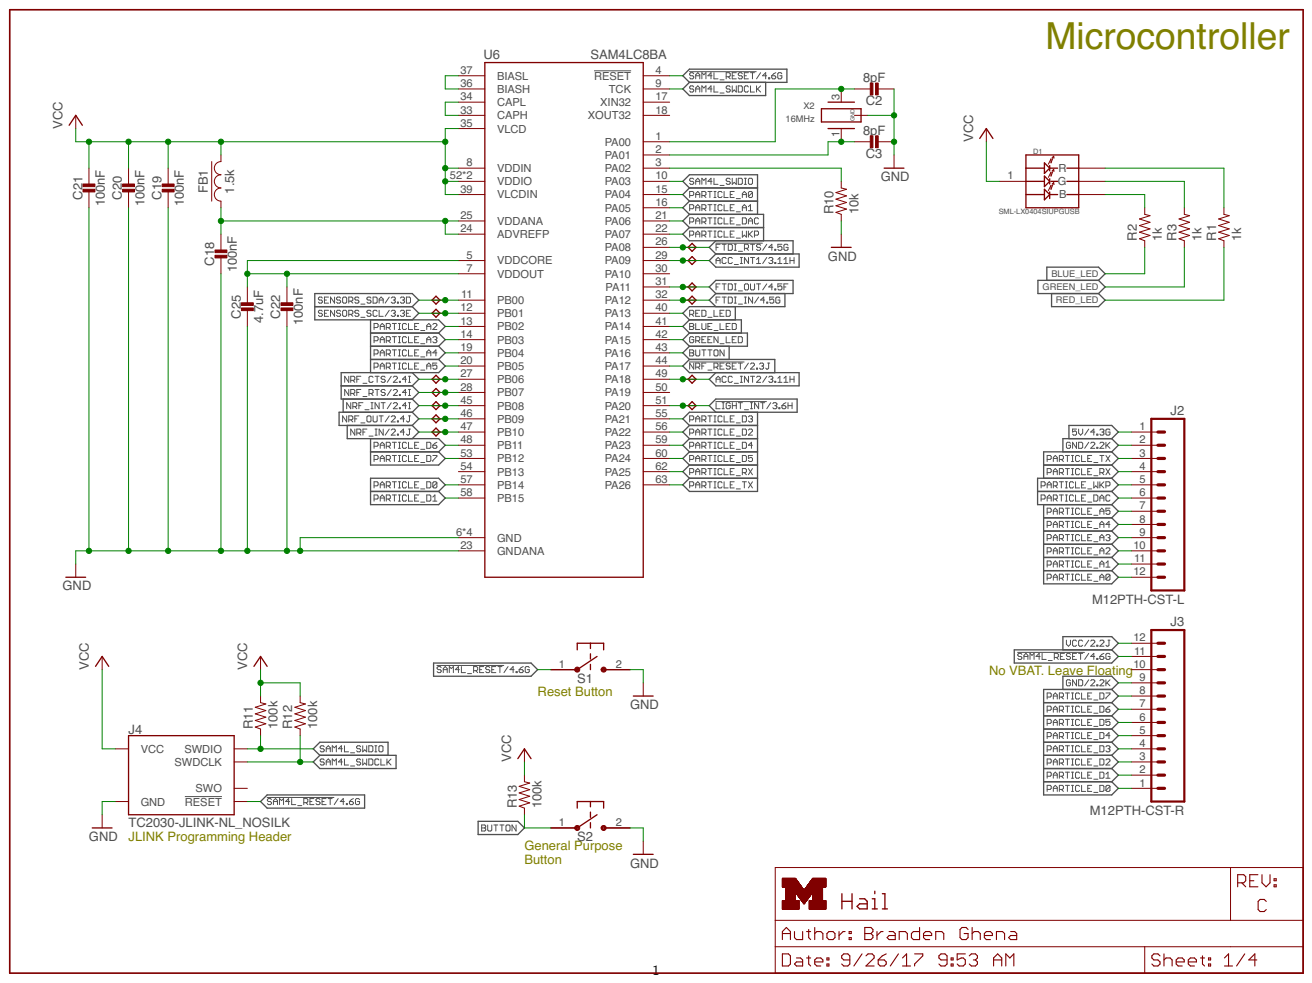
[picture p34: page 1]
Microcontroller JLINK Programming Header; Reset Button General Purpose Button; No VBAT. Leave Floating GND; 100k VCC; VCC TC2030-JLINK-NL_NOSILK; SML-LX0404SIUPGUSB; 1k VCC; M12PTH-CST-L M12PTH-CST-R GND 100k VCC; GND SAM4LC8BA GND; 100nF 4.7uF VCC; 10k GND 8pF 8pF ¹⁶MHz; GND R¹¹; R¹² SWDIO SWDCLK SWO RESET VCC GND J4; RGB; 2 R¹³ GND 6*4; VDDCORE 5; VDDOUT 7; VDDIN 8; ADVREFP 24; VDDANA 25; VDDIO 52*2; GNDANA 23; RESET; 4 TCK; 9 XIN32; 17 XOUT32; 63 VLCDIN 39; VLCD 35; BIASL 37; BIASH 36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


# Sensors


# Power and USB

GND; FT231XQ GND; MAX8887EZK33+T; GND GND; MICRO_USB_B_HIROSE_ZX62R-B-5P; ID GND; 3V3OUT; USBD- 9; USBD+; RESET; VCCIO; 20 VCC; 12 TXD; 17 RXD 1 RTS 19 CTS 6 DTR 18 DSR 4 DCD; 2 CBUS0; 15 GND; 3*3 CBUS1; 14 CBUS2 7 CBUS3 16; OUT SHDN

## Top and Bottom Layers


## Top Layer


## Bottom Layer


## Top Copper Layer


## Layer 2 Copper


## Layer 3 Copper


## Bottom Copper Layer


## Top Paste Layer with Silkscreen


## Bottom Paste Layer with Silkscreen


## Top and Bottom Layers 1:1 Scale


## Top Layer 1:1 Scale

## Layer 2 Copper 1:1 Scale

## Layer 3 Copper 1:1 Scale

## Bottom Copper Layer 1:1 Scale


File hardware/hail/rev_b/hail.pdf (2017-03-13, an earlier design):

Microcontroller JLINK Programming Header; Reset Button General Purpose Button; No VBAT. Leave Floating GND; 100k VCC; VCC TC2030-JLINK-NL_NOSILK; SML-LX0404SIUPGUSB; 1k VCC; M12PTH-CST-L M12PTH-CST-R GND 100k VCC; GND SAM4LC8BA GND; 100nF 4.7uF VCC; 10k GND 8pF 8pF ¹⁶MHz; GND R¹¹; R¹² SWDIO SWDCLK SWO RESET VCC GND J4; RGB; 2 R¹³ GND 6*4; VDDCORE 5; VDDOUT 7; VDDIN 8; ADVREFP 24; VDDANA 25; VDDIO 52*2; GNDANA 23; RESET; 4 TCK; 9 XIN32; 17 XOUT32; 63 VLCDIN 39; VLCD 35; BIASL 37; BIASH 36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


# Sensors


# Power and USB

GND; FT231XQ GND; MAX8887EZK33+T; GND GND; VCC; MICRO_USB_B_HIROSE_ZX62R-B-5P; ID GND; 3V3OUT; USBD- 9; USBD+; RESET; VCCIO; 20 VCC; 12 TXD 17 RXD 1 RTS 19 CTS 6 DTR 18 DSR 4 DCD; 2 CBUS0; 15 GND 3*3 CBUS1; 14 CBUS2 7 CBUS3 16; OUT SHDN; BP U4 C²³


Top and Bottom Layers

Top Layer

Bottom Layer


Top Copper Layer

Layer 2 Copper

Layer 3 Copper


Bottom Copper Layer


Top Paste Layer with Silkscreen


Bottom Paste Layer with Silkscreen


Top and Bottom Layers 1:1 Scale

Top Layer 1:1 Scale

Layer 2 Copper 1:1 Scale

Layer 3 Copper 1:1 Scale


Bottom Copper Layer 1:1 Scale

### hail_bom

Qty Value | Device
1 FRACTUS-2.4GHZ-FR05-S1-N-0-110FRACTUS-2.4GHZ-FR05-S1-N-0-110
1 BAL-NRF01D3 | BAL-NRF01D3
11.5pF | CAPACITOR0402_CAP
28pF | CAPACITOR0402_CAP
212pF | CAPACITOR0402_CAP
11nF | CAPACITOR0402_CAP
12.2nF | CAPACITOR0402_CAP
110nF | CAPACITOR0402_CAP
147nF | CAPACITOR0402_CAP
13100nF | CAPACITOR0402_CAP
34.7uF | CAPACITOR0402_CAP
1 SML-LX0404SIUPGUSB | SML-LX0404SIUPGUSB
11.5k | FERRITE_BEAD0402
1 MICRO_USB_B_HIROSE_ZX62R-B-5MICRO_USB_B_HIROSE_ZX62R-B-5
1 M12PTH-CST-L | M12PTH-CST-L
1 M12PTH-CST-R | M12PTH-CST-R
2 TC2030-JLINK-NL_NOSILK | TC2030-JLINK-NL_NOSILK
16.8nH | INDUCTOR0402
1LED0603 | LED0603
61k | RESISTOR0402_RES
410k | RESISTOR0402_RES
3100k | RESISTOR0402_RES
2 B3U-1000P | B3U-1000P
13 TPB1,27 | TPB1,27
1 FT231XQ | FT231XQ
1 FXOS8700CQ | FXOS8700CQ
1ISL29035 | ISL29035
1 MAX8887EZK33+T | MAX8887EZK33+T
1 NRF51822QF | NRF51822QF
1 SAM4LC8BA | SAM4LC8BA
1 SI7021 | SI7021
116MHz | TXC-8Y
116MHz | FH1600015

### hail_bom

Package
FRACTUS-ANTENNA-FR05-S1-N-0-110 BAL-NRF01D3
0402_CAP
0402_CAP
0402_CAP
0402_CAP
0402_CAP
0402_CAP
0402_CAP
0402_CAP
0402_CAP
1MM_SQ_4PAD
0402_CAP
USB_MICRO_B-HIROSE-ZX62R-B-5P 1X12-CASTELLATED
1X12-CASTELLATED
TC2030-IDC-NL_NOSILK
0402_CAP
LED-0603
0402_RES
0402_RES
0402_RES
B3U-1000P
B1,27
QFN-20-4MM
QFN-16-3MM
ODFN-6-1.5MMX1.6MM
SOT-23-5
QFN-48-6MM
QFN-64-9MM
DFN-6/3MM
TXC-8Y
FHXXX

### hail_bom

Parts
A1
B1
C1
C2, C3
C4, C5
C6
C7
C8
C9
C10, C11, C12, C13, C14, C15, C16, C17, C18, C19, C20, C21, C22 C23, C24, C25
D1
FB1
J1
J2
J3
J4, J5
L1
LED1
R1, R2, R3, R4, R5, R6
R7, R8, R9, R10
R11, R12, R13
S1, S2
TP1, TP2, TP3, TP4, TP5, TP6, TP7, TP8, TP9, TP10, TP11, TP12, TP13 U1
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
### hail_bom

Description | DIGIKEY
Fractus Micro Reach Xtend
50 ohm nominal input / conjugate match balun to nRF51422-QFAA, 497-13637-1-ND
0402 Capacitor | 490-6212-1-ND
0402 Capacitor | 490-8230-1-ND
0402 Capacitor | 490-6197-1-ND
0402 Capacitor | 490-1303-1-ND
0402 Capacitor | 490-5419-1-ND
0402 Capacitor | 490-7763-1-ND
0402 Capacitor | 445-1264-1-ND
0402 Capacitor | 490-10777-1-ND
0402 Capacitor | 490-13252-1-ND
1mm^2 RGB LED | 67-2125-1-ND
| 1276-6395-1-ND
USB Micro B Connector | H125274CT-ND
Header 12 | S1011E-12-ND
Header 12 | S1011E-12-ND
A very specific inductor | 490-6840-1-ND
LED | 160-1837-6-ND
Resistor | 1276-3430-1-ND
Resistor | 1276-3431-1-ND
Resistor | 1276-3432-1-ND
Switch | SW1020CT-ND
Test pad
USB Bridge, USB to UART USB 2.0 UART Interface | 768-1128-1-ND
Accelerometer, Magnetometer, 3 Axis Sensor, I2C/SPI | FXOS8700CQR1CT-ND
Optical Sensor Ambient 550nm I2C | ISL29035IROZ-T7CT-ND
IC REG LDO 3.3V 0.3A TSOT23-5 | MAX8887EZK33+TCT-ND
Multiprotocol Bluetooth 4.0 low energy/2.4 GHz RF SoC | 1490-1049-1-ND
SAM4L Microcontroller. 64QFN Package. 512 Flash. | ATSAM4LC8BA-MURCT-ND
IC TEMP SENSOR RH 2% DFN | 336-3141-ND
2mmx1.6mm SMD Crystal | 887-2003-1-ND
Pericom Type FH 16 MHz 2.5 x 2.0 mm | FH1600015CT-ND
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

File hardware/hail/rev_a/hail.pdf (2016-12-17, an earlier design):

1 | Microcontroller JLINK Programming Header | Reset Button General Purpose Button | No VBAT. Leave Floating GND | 100k | 100k VCC | VCC TC2030-JLINK-NL_NOSILK | SML-LX0404SIUPGUSB | 1k1k | 1k VCC | M12PTH-CST-L M12PTH-CST-R GND 100k VCC | GND SAM4LC8BA GND | 100nF 100nF 100nF 100nF | 100nF 4.7uF VCC | 10k GND 8pF 8pF ¹⁶MHz | GND R¹⁰ | R¹¹ SWDIO SWDCLK SWO RESET VCC GND J2 | D1 1 | RGB | R¹ R² | R³ JP3 121110987654321 JP4 123456789101112 S1 ¹ | 2 S2 ¹ | 2 R¹² GND 6*4 | VDDCORE 5 | VDDOUT 7 | VDDIN 8 | ADVREFP 24 | VDDANA 25 | VDDIO 52*2 | GNDANA 23 | RESET | 4 TCK | 9 XIN32 | 17 XOUT32 | 18 PA00 | 1 PA01 | 2 PA02 | 3 PA03 | 10 PA04 | 15 PA05 | 16 PA06 | 21 PA07 | 22 PA08 | 26 PA09 | 29 PA10 | 30 PA11 | 31 PA12 | 32 PA13 | 40 PA14 | 41 PA15 | 42 PA16 | 43 PA17 | 44 PA18 | 49 PA19 | 50 PA20 | 51 PA21 | 55 PA22 | 56 PA23 | 59 PA24 | 60 PA25 | 62 PA26 | 63 VLCDIN 39 | VLCD 35 | BIASL 37 | BIASH 36 | CAPL 34 | CAPH 33 U6PB15 58 | PB14 57 | PB12 53 | PB13 54 | PB11 48 | PB10 47 | PB09 46 | PB08 45 | PB07 28 | PB06 27 | PB05 20 | PB04 19 | PB03 14 | PB02 13 | PB01 12 | PB00 11 C¹⁸ C¹⁹ C²⁰ C²¹ | FB¹ 1.5k | C²² C²⁵ | R⁹ | C2 C3 ¹ ³ GNDX2 | RED_LED BLUE_LED GREEN_LED


2 | BLE Radio JLINK Programming Header | PIN1 | PIN12 | PIN35 NRF51822QF | BAL-NRF01D3 TC2030-JLINK-NL_NOSILK | 16MHz 12pF | 12pF GND 100nF 47nF GND | GND ¹nF VCC | GND ¹⁰⁰nF | 100nF 1k GND | GND | 2.2nF GND | GND | 6.8nH 1.5pF GND VCC GND | LED⁰⁶⁰³ 1k VCC | VDD ¹*2 GND 13*4 P00/AREF0 4 | P01/AIN2 5 | DCC 2 | P02/AIN3 6 | P03/AIN4 7 | P04/AIN5 8 | P05/AIN6 9 | P06/AIN7/AREF1 10 | P07 11 | XC1 | 37 XC2 | 38 P08 14 | P09 15 | P10 16 | P11 17 | P12 18 | P13 19 | P14 20 | P15 21 | P16 | 22 P17 | 25 P18 | 26 P19 | 27 P20 | 28 P21 | 40 P22 | 41 P23 | 42 P24 | 43 P25 | 44 P26/AIN0/XL2 | 45 P27/AIN1/XL1 | 46 P28 | 47 P29 | 48 SWDIO/RESET 23 | SWDCLK 24 | DEC1 | 39 DEC2 | 29 ANT1 | 31 ANT2 | 32 VDD_PA | 30 AVDD ³⁵*2 U5 | P30 | 3 | ANT1 ANT2 VDD_PA | SE GND B1 SWDIO SWDCLK SWO RESET VCC GND J3 | 1 | 3 X1GND C⁴ | C⁵ C¹⁰ C⁹ C⁶ C¹¹ | C¹² R⁴ | C⁷ | L1 C¹ LED¹ R⁵


# Sensors


# Power and USB

GND; FT231XQ GND; MAX8887EZK33+T; GND GND; VCC; MICRO_USB_B_HIROSE_ZX62R-B-5P; ID GND; 3V3OUT; USBD- 9; USBD+; RESET; VCCIO; 20 VCC; 12 TXD 17 RXD 1 RTS 19 CTS 6 DTR 18 DSR 4 DCD; 2 CBUS0; 15 GND 3*3 CBUS1; 14 CBUS2 7 CBUS3 16; OUT SHDN; BP U4 C²³

## Top and Bottom Layers


## Top Layer


## Bottom Layer


## Top Copper Layer


## Layer 2 Copper


## Layer 3 Copper


## Bottom Copper Layer


## Top Paste Layer with Silkscreen


## Bottom Paste Layer with Silkscreen


## Top and Bottom Layers 1:1 Scale


## Top Layer 1:1 Scale

## Layer 2 Copper 1:1 Scale

## Layer 3 Copper 1:1 Scale

## Bottom Copper Layer 1:1 Scale


hail_bom

Page 1
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

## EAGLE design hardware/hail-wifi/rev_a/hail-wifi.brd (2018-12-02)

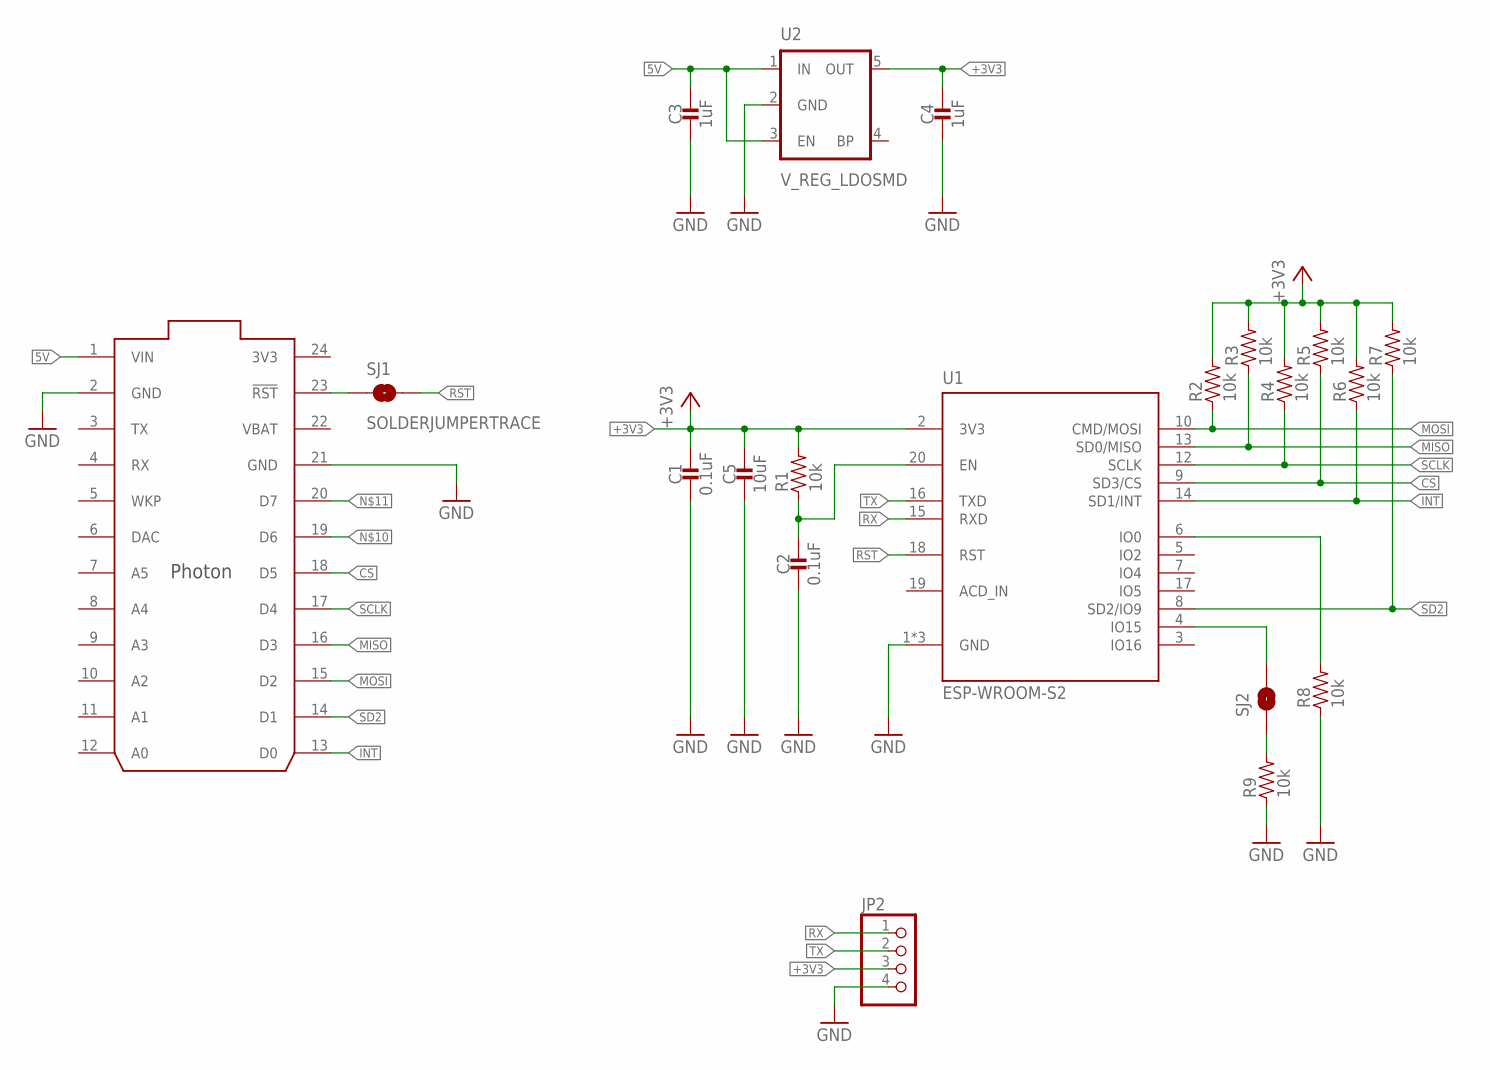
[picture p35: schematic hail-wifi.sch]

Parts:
C1, C2: 0.1uF; 0603_CAP
C3, C4: 1uF; 0603_CAP
C5: 10uF; 0603_CAP
JP2: PINHD-1X4/90; 1X04/90
R1, R2, R3, R4, R5, R6, R7, R8, R9: 10k; 0603-RES
SJ1: SOLDERJUMPERTRACE; SJ_2S-TRACE
SJ2: SOLDERJUMPERNO; SJ_2S-NO
U1: ESP-WROOM-S2
U2: V_REG_LDOSMD; SOT23-5
U3: PHOTON_WITH_HEADERS; PHOTON

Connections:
3V3: U3.24 (3V3)
5V: C3.1, U2.1 (IN), U2.3 (EN), U3.1 (VIN)
+3V3: C1.1, C4.1, C5.1, JP2.3, R1.2, R2.2, R3.2, R4.2, R5.2, R6.2, R7.2, U1.2 (3V3), U2.5 (OUT)
CS: R5.1, U1.9 (SD3/CS), U3.18 (D5)
GND: C1.2, C2.2, C3.2, C4.2, C5.2, JP2.4, R8.1, R9.1, U1.1 (GND), U1.11 (GND), U1.21 (GND), U2.2 (GND), U3.2 (GND), U3.21 (GND)
INT: R6.1, U1.14 (SD1/INT), U3.13 (D0)
MISO: R3.1, U1.13 (SD0/MISO), U3.16 (D3)
MOSI: R2.1, U1.10 (CMD/MOSI), U3.15 (D2)
unnamed: SJ2.2, U1.4 (IO15)
unnamed: SJ1.1, U3.23 (!RST)
unnamed: R9.2, SJ2.1
unnamed: R8.2, U1.6 (IO0)
unnamed: C2.1, R1.1, U1.20 (EN)
RST: SJ1.2, U1.18 (RST)
RX: JP2.1, U1.15 (RXD)
SCLK: R4.1, U1.12 (SCLK), U3.17 (D4)
SD2: R7.1, U1.8 (SD2/IO9), U3.14 (D1)
TX: JP2.2, U1.16 (TXD)
VBAT: U3.22 (VBAT)

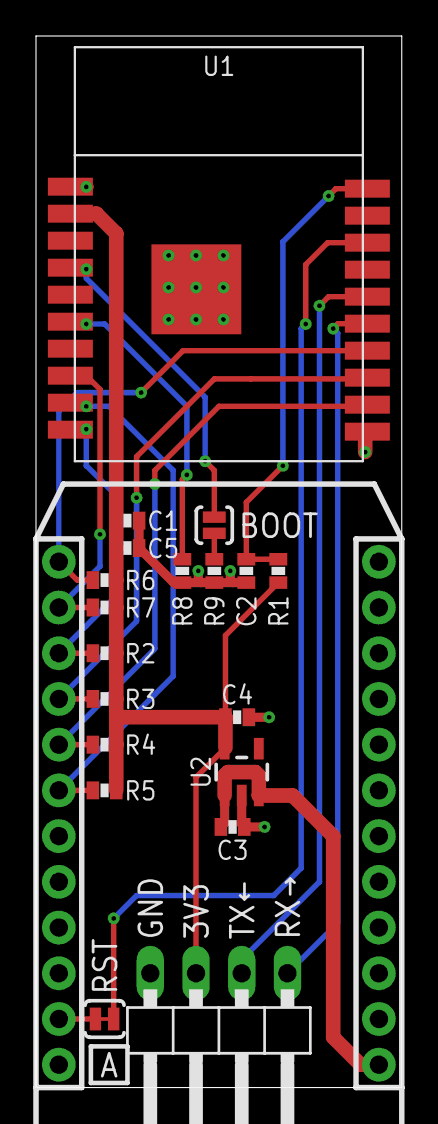
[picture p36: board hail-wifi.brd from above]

Board: 2 copper layers, 20.3 x 58.4 mm, 20 parts (0 on the bottom side), 17 nets.

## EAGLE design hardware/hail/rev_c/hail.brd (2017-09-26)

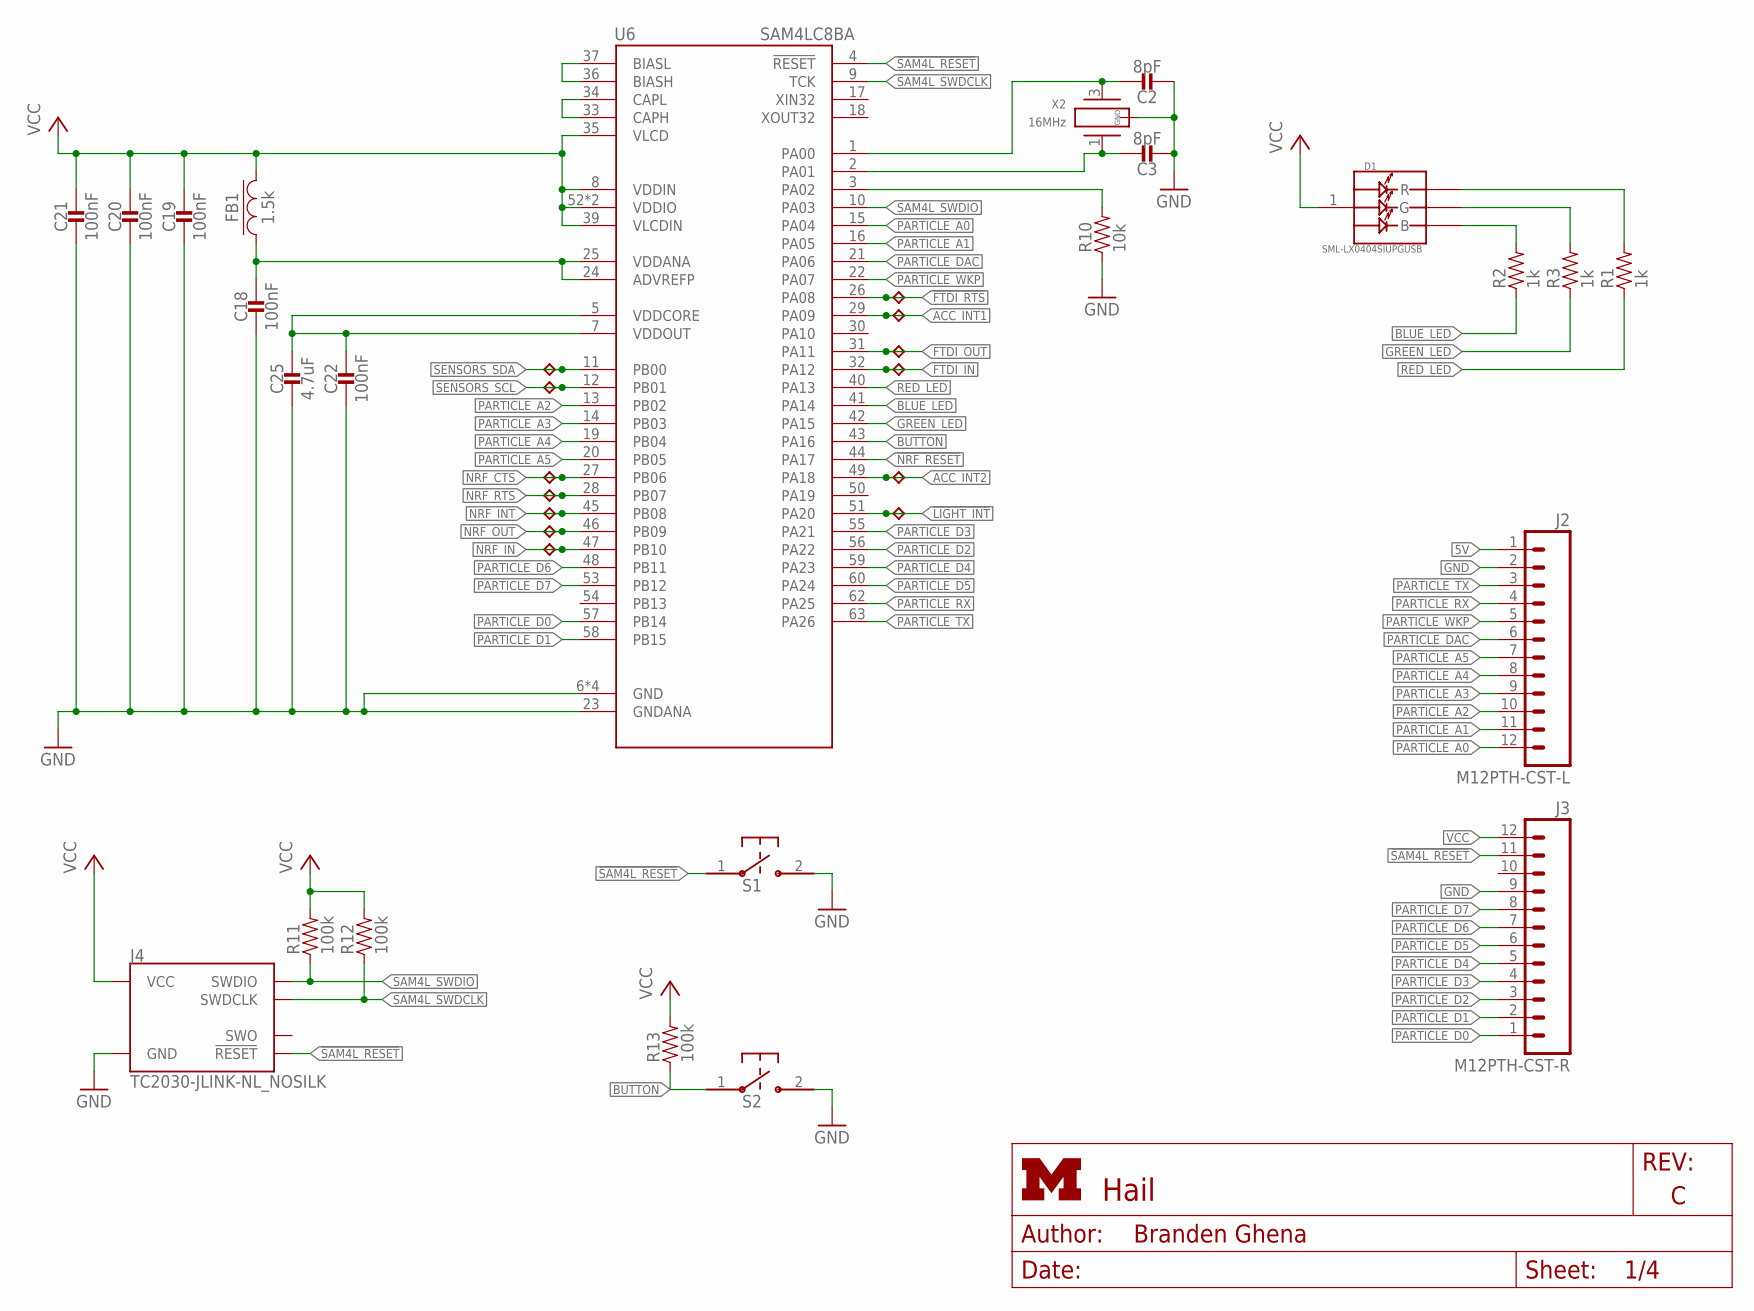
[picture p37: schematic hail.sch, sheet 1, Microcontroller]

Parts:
C2, C3: 8pF; 0402_CAP; MPN GRM1555C1H8R0BA01D; DIGIKEY 490-8230-1-ND
C18, C19, C20, C21, C22: 100nF; 0402_CAP; MPN MF-CAP-0402-0.1uF; DIGIKEY 490-10777-1-ND
C25: 4.7uF; 0402_CAP; MPN ZRB15XR61A475KE01D; DIGIKEY 490-13252-1-ND
D1: SML-LX0404SIUPGUSB; 1MM_SQ_4PAD; MPN SML-LX0404SIUPGUSB
FB1: 1.5k; 0402_CAP; MPN CIM05J152NC; DIGIKEY 1276-6395-1-ND
J2: M12PTH-CST-L; 1X12-CASTELLATED; MPN MF-CON-2.54mm-01x12; DIGIKEY S1011E-12-ND
J3: M12PTH-CST-R; 1X12-CASTELLATED; MPN MF-CON-2.54mm-01x12; DIGIKEY S1011E-12-ND
J4: TC2030-JLINK-NL_NOSILK; TC2030-IDC-NL_NOSILK
R1, R2, R3: 1k; 0402_RES; MPN MF-RES-0402-1K; DIGIKEY 1276-3430-1-ND
R10: 10k; 0402_RES; MPN MF-RES-0402-10K; DIGIKEY 1276-3431-1-ND
R11, R12, R13: 100k; 0402_RES; MPN MF-RES-0402-100K; DIGIKEY 1276-3432-1-ND
S1, S2: B3U-1000P; MPN B3U-1000P
TP1, TP2, TP3, TP4, TP5, TP6, TP7, TP8, TP9, TP10, TP11, TP12, TP13: TPB1,27; B1,27
U6: SAM4LC8BA; QFN-64-9MM; MPN ATSAM4LC8BA-MU; DIGIKEY ATSAM4LC8BA-MURCT-ND
X2: 16MHz; FHXXX; MPN FH1600015

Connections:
5V: J2.1 (12); also elsewhere on the board
!FTDI_RTS: TP11.TP, U6.26 (PA08); also elsewhere on the board
!LIGHT_INT: TP10.TP, U6.51 (PA20); also elsewhere on the board
!NRF_RESET: U6.44 (PA17); also elsewhere on the board
!SAM4L_RESET: J3.11, J4.3 (!RESET), S1.1, U6.4 (!RESET); also elsewhere on the board
ACC_INT1: TP8.TP, U6.29 (PA09); also elsewhere on the board
ACC_INT2: TP9.TP, U6.49 (PA18); also elsewhere on the board
BLUE_LED: R2.1, U6.41 (PA14)
BUCK/LDO_N1: R10.2, U6.3 (PA02)
BUTTON: R13.1, S2.1, U6.43 (PA16)
FTDI_IN: TP13.TP, U6.32 (PA12); also elsewhere on the board
FTDI_OUT: TP12.TP, U6.31 (PA11); also elsewhere on the board
GND: C2.2, C3.2, C18.2, C19.2, C20.2, C21.2, C22.2, C25.2, J2.2 (11), J3.9, J4.5 (GND), R10.1, S1.2, S2.2, U6.6 (GND), U6.23 (GNDANA), U6.38 (GND), U6.64 (GND), U6.GND, X2.2 (GND), X2.4 (GND); also elsewhere on the board
GREEN_LED: R3.1, U6.42 (PA15)
unnamed: D1.3 (B), R2.2
unnamed: D1.4 (G), R3.2
unnamed: D1.2 (R), R1.2
unnamed: U6.36 (BIASH), U6.37 (BIASL)
unnamed: U6.33 (CAPH), U6.34 (CAPL)
unnamed: C18.1, FB1.1, U6.24 (ADVREFP), U6.25 (VDDANA)
unnamed: C22.1, C25.1, U6.5 (VDDCORE), U6.7 (VDDOUT)
NRF_CTS: TP1.TP, U6.27 (PB06); also elsewhere on the board
NRF_IN: TP5.TP, U6.47 (PB10); also elsewhere on the board
NRF_INT: TP3.TP, U6.45 (PB08); also elsewhere on the board
NRF_OUT: TP4.TP, U6.46 (PB09); also elsewhere on the board
NRF_RTS: TP2.TP, U6.28 (PB07); also elsewhere on the board
PARTICLE_A0: J2.12 (1), U6.15 (PA04)
PARTICLE_A1: J2.11 (2), U6.16 (PA05)
PARTICLE_A2: J2.10 (3), U6.13 (PB02)
PARTICLE_A3: J2.9 (4), U6.14 (PB03)
PARTICLE_A4: J2.8 (5), U6.19 (PB04)
PARTICLE_A5: J2.7 (6), U6.20 (PB05)
PARTICLE_D0: J3.1, U6.57 (PB14)
PARTICLE_D1: J3.2, U6.58 (PB15)
PARTICLE_D2: J3.3, U6.56 (PA22)
PARTICLE_D3: J3.4, U6.55 (PA21)
PARTICLE_D4: J3.5, U6.59 (PA23)
PARTICLE_D5: J3.6, U6.60 (PA24)
PARTICLE_D6: J3.7, U6.48 (PB11)
PARTICLE_D7: J3.8, U6.53 (PB12)
PARTICLE_DAC: J2.6 (7), U6.21 (PA06)
PARTICLE_RX: J2.4 (9), U6.62 (PA25)
PARTICLE_TX: J2.3 (10), U6.63 (PA26)
PARTICLE_WKP: J2.5 (8), U6.22 (PA07)
RED_LED: R1.1, U6.40 (PA13)
SAM4L_SWDCLK: J4.4 (SWDCLK), R12.1, U6.9 (TCK)
SAM4L_SWDIO: J4.2 (SWDIO), R11.1, U6.10 (PA03)
SAM4L_XIN1: C2.1, U6.1 (PA00), X2.3 (2)
SAM4L_XOUT1: C3.1, U6.2 (PA01), X2.1
SENSORS_SCL: TP7.TP, U6.12 (PB01); also elsewhere on the board
SENSORS_SDA: TP6.TP, U6.11 (PB00); also elsewhere on the board
VCC: C19.1, C20.1, C21.1, D1.1 (VDD), FB1.2, J3.12, J4.1 (VCC), R11.2, R12.2, R13.2, U6.8 (VDDIN), U6.35 (VLCD), U6.39 (VLCDIN), U6.52 (VDDIO), U6.61 (VDDIO); also elsewhere on the board

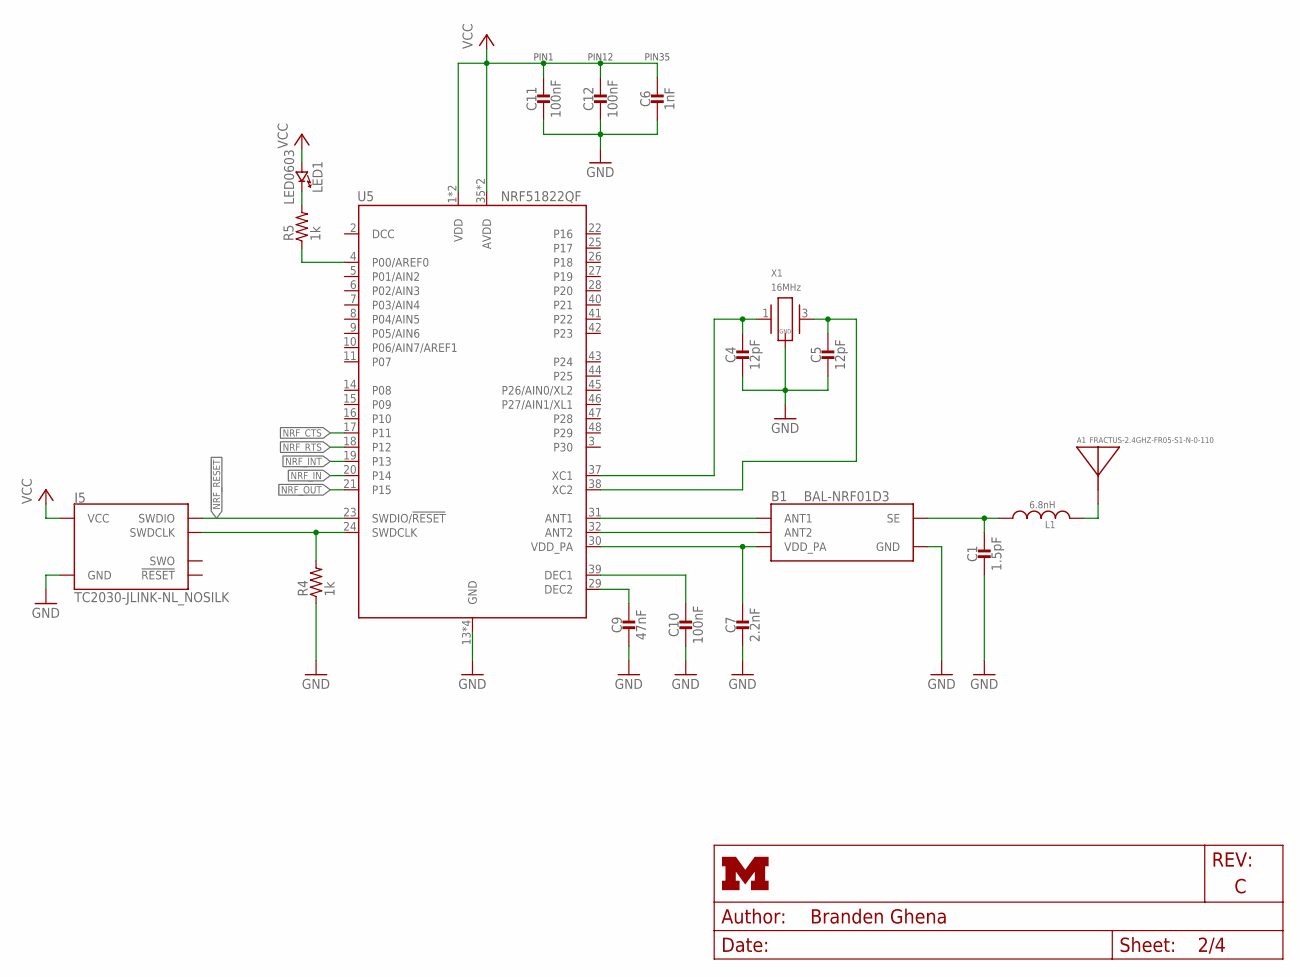
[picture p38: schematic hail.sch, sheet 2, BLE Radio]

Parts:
A1: FRACTUS-2.4GHZ-FR05-S1-N-0-110; FRACTUS-ANTENNA-FR05-S1-N-0-110; MPN FR05-S1-N-0110B
B1: BAL-NRF01D3; MPN BAL-NRF01D3
C1: 1.5pF; 0402_CAP; MPN GRM1555C1H1R5BA01D; DIGIKEY 490-6212-1-ND
C4, C5: 12pF; 0402_CAP; MPN GRM1555C1H120GA01D; DIGIKEY 490-6197-1-ND
C6: 1nF; 0402_CAP; MPN MF-CAP-0402-1nF; DIGIKEY 490-1303-1-ND
C7: 2.2nF; 0402_CAP; MPN GRM155R71E222KA01D; DIGIKEY 490-5419-1-ND
C9: 47nF; 0402_CAP; MPN C1005X7R1C473K050BC; DIGIKEY 445-1264-1-ND
C10, C11, C12: 100nF; 0402_CAP; MPN MF-CAP-0402-0.1uF; DIGIKEY 490-10777-1-ND
J5: TC2030-JLINK-NL_NOSILK; TC2030-IDC-NL_NOSILK
L1: 6.8nH; 0402_CAP; MPN LQW15AN6N8G00D; DIGIKEY 490-6840-1-ND
LED1: LED0603; LED-0603; MPN MF-LED-0603-GREEN; DIGIKEY 160-1837-6-ND
R4, R5: 1k; 0402_RES; MPN MF-RES-0402-1K; DIGIKEY 1276-3430-1-ND
U5: NRF51822QF; QFN-48-6MM; MPN NRF51822-QFAC-R7; DIGIKEY 1490-1049-1-ND
X1: 16MHz; TXC-8Y; MPN 8Y-16.000MAAV-T; DIGIKEY 887-2003-1-ND

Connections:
!NRF_RESET: J5.2 (SWDIO), U5.23 (SWDIO/!RESET); also elsewhere on the board
GND: B1.GND, C1.2, C4.2, C5.2, C6.2, C7.2, C9.2, C10.2, C11.2, C12.2, J5.5 (GND), R4.1, U5.13 (GND), U5.33 (GND), U5.34 (GND), U5.GND, X1.2 (GND), X1.4 (GND); also elsewhere on the board
unnamed: C10.1, U5.39 (DEC1)
unnamed: C9.1, U5.29 (DEC2)
unnamed: J5.4 (SWDCLK), R4.2, U5.24 (SWDCLK)
unnamed: R5.1, U5.4 (P00/AREF0)
unnamed: LED1.C (CATHODE), R5.2
unnamed: B1.ANT1, U5.31 (ANT1)
unnamed: B1.VCC (VDD_PA), C7.1, U5.30 (VDD_PA)
unnamed: B1.ANT2, U5.32 (ANT2)
unnamed: C4.1, U5.37 (XC1), X1.1
unnamed: C5.1, U5.38 (XC2), X1.3 (2)
unnamed: B1.SE, C1.1, L1.1
unnamed: A1.ANT, L1.2
NRF_CTS: U5.17 (P11); also elsewhere on the board
NRF_IN: U5.20 (P14); also elsewhere on the board
NRF_INT: U5.19 (P13); also elsewhere on the board
NRF_OUT: U5.21 (P15); also elsewhere on the board
NRF_RTS: U5.18 (P12); also elsewhere on the board
VCC: C6.1, C11.1, C12.1, J5.1 (VCC), LED1.A (ANODE), U5.1 (VDD), U5.12 (VDD), U5.35 (AVDD), U5.36 (AVDD); also elsewhere on the board

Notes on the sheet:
PIN35
PIN1
PIN12

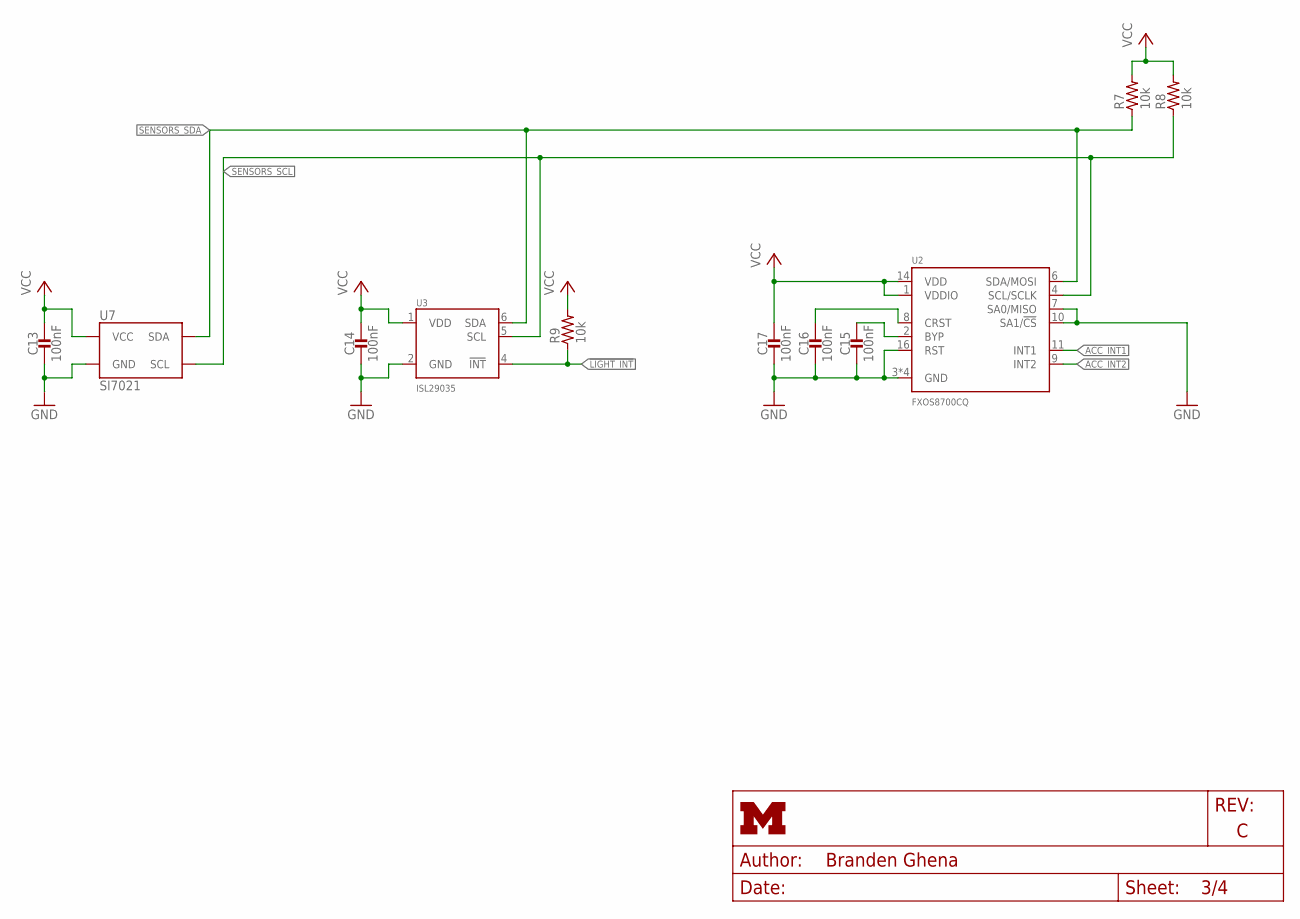
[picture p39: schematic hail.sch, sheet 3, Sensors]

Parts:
C13, C14, C15, C16, C17: 100nF; 0402_CAP; MPN MF-CAP-0402-0.1uF; DIGIKEY 490-10777-1-ND
R7, R8, R9: 10k; 0402_RES; MPN MF-RES-0402-10K; DIGIKEY 1276-3431-1-ND
U2: FXOS8700CQ; QFN-16-3MM
U3: ISL29035; ODFN-6-1.5MMX1.6MM
U7: SI7021; DFN-6/3MM; MPN SI7021-A20-GM1; DIGIKEY 336-3141-ND

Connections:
!LIGHT_INT: R9.1, U3.4 (!INT); also elsewhere on the board
ACC_INT1: U2.11 (INT1); also elsewhere on the board
ACC_INT2: U2.9 (INT2); also elsewhere on the board
GND: C13.2, C14.2, C15.2, C16.2, C17.2, U2.3 (GND), U2.5 (GND), U2.7 (SA0/MISO), U2.10 (SA1/!CS), U2.12 (GND), U2.13 (GND), U2.16 (RST), U3.2 (GND), U7.2 (GND); also elsewhere on the board
unnamed: C15.1, U2.2 (BYP)
unnamed: C16.1, U2.8 (CRST)
SENSORS_SCL: R8.1, U2.4 (SCL/SCLK), U3.5 (SCL), U7.6 (SCL); also elsewhere on the board
SENSORS_SDA: R7.1, U2.6 (SDA/MOSI), U3.6 (SDA), U7.1 (SDA); also elsewhere on the board
VCC: C13.1, C14.1, C17.1, R7.2, R8.2, R9.2, U2.1 (VDDIO), U2.14 (VDD), U3.1 (VDD), U7.5 (VCC); also elsewhere on the board

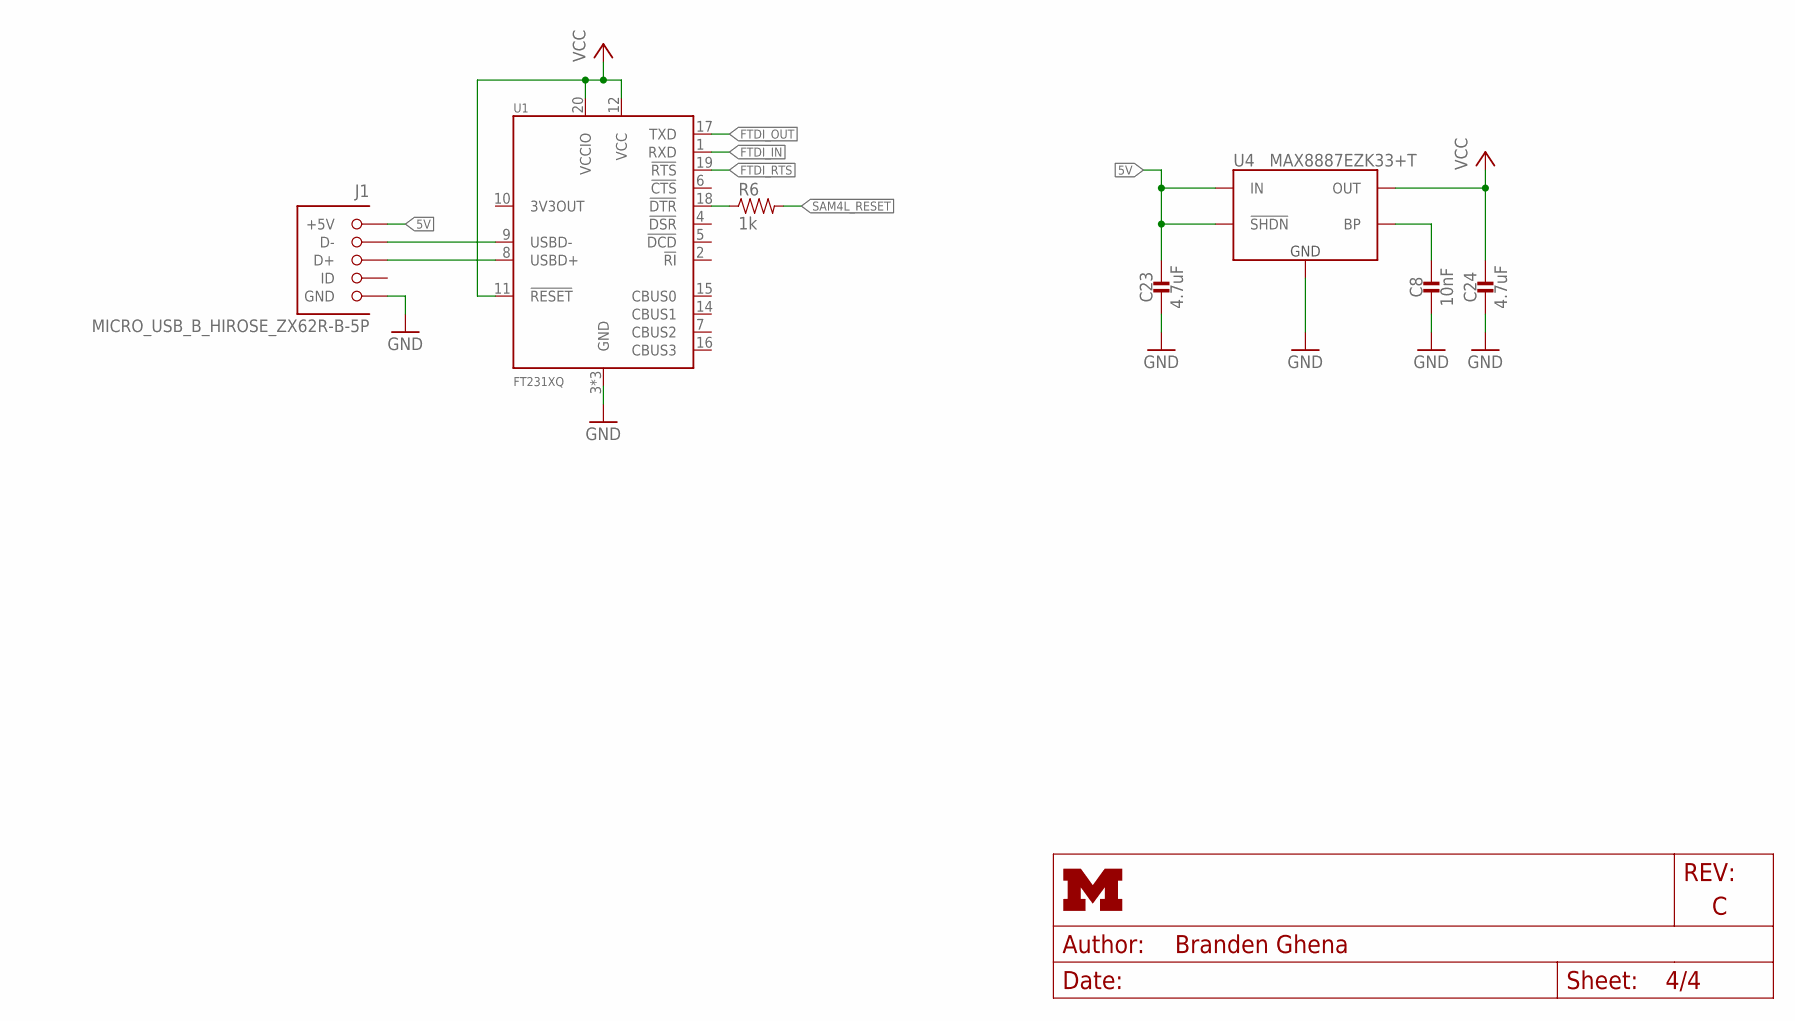
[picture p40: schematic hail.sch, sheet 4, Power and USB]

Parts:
C8: 10nF; 0402_CAP; MPN MF-CAP-0402-0.01uF; DIGIKEY 490-7763-1-ND
C23, C24: 4.7uF; 0402_CAP; MPN ZRB15XR61A475KE01D; DIGIKEY 490-13252-1-ND
J1: MICRO_USB_B_HIROSE_ZX62R-B-5P; USB_MICRO_B-HIROSE-ZX62R-B-5P; MPN ZX62R-B-5P(30); DIGIKEY H125274CT-ND
R6: 1k; 0402_RES; MPN MF-RES-0402-1K; DIGIKEY 1276-3430-1-ND
U1: FT231XQ; QFN-20-4MM
U4: MAX8887EZK33+T; SOT-23-5; MPN MAX8887EZK33+T

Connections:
5V: C23.1, J1.1 (+5V), U4.1 (IN), U4.3 (!SHDN); also elsewhere on the board
!FTDI_RTS: U1.19 (!RTS); also elsewhere on the board
!SAM4L_RESET: R6.2; also elsewhere on the board
FTDI_IN: U1.1 (RXD); also elsewhere on the board
FTDI_OUT: U1.17 (TXD); also elsewhere on the board
GND: C8.2, C23.2, C24.2, J1.5 (GND), U1.3 (GND), U1.13 (GND), U1.GND, U4.2 (GND); also elsewhere on the board
unnamed: J1.2 (D-), U1.9 (USBD-)
unnamed: J1.3 (D+), U1.8 (USBD+)
unnamed: C8.1, U4.4 (BP)
unnamed: R6.1, U1.18 (!DTR)
VCC: C24.1, U1.11 (!RESET), U1.12 (VCC), U1.20 (VCCIO), U4.5 (OUT); also elsewhere on the board

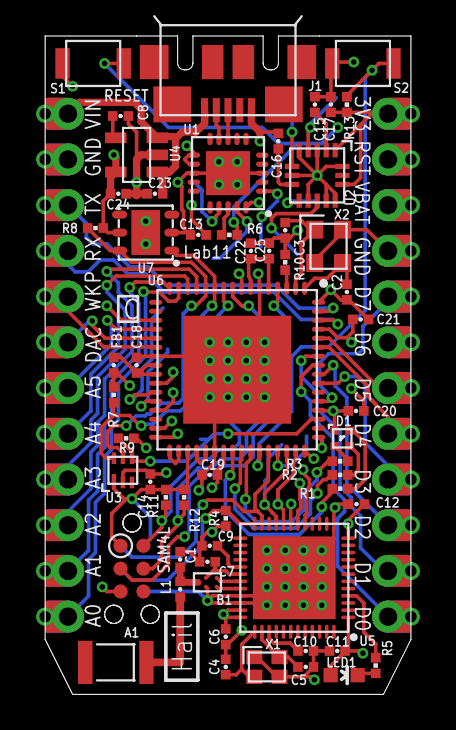
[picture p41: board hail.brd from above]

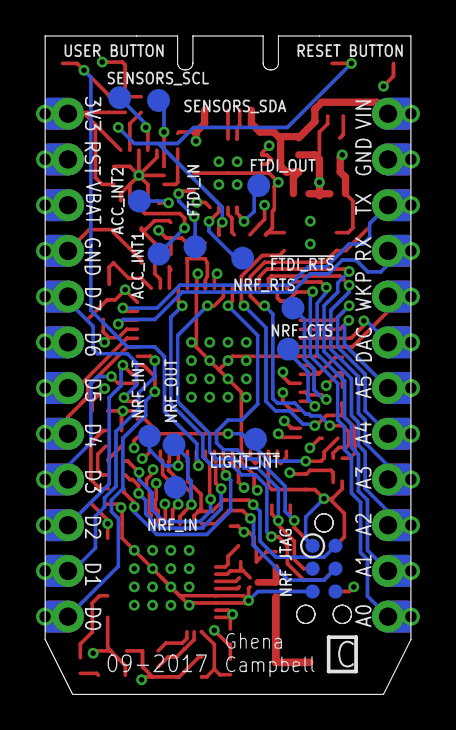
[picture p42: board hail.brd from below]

Board: 4 copper layers, 20.3 x 36.6 mm, 75 parts (14 on the bottom side), 70 nets.

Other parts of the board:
U$1: PHOTON-BOTTOM-SS
U$2: PHOTON-TOP-SS

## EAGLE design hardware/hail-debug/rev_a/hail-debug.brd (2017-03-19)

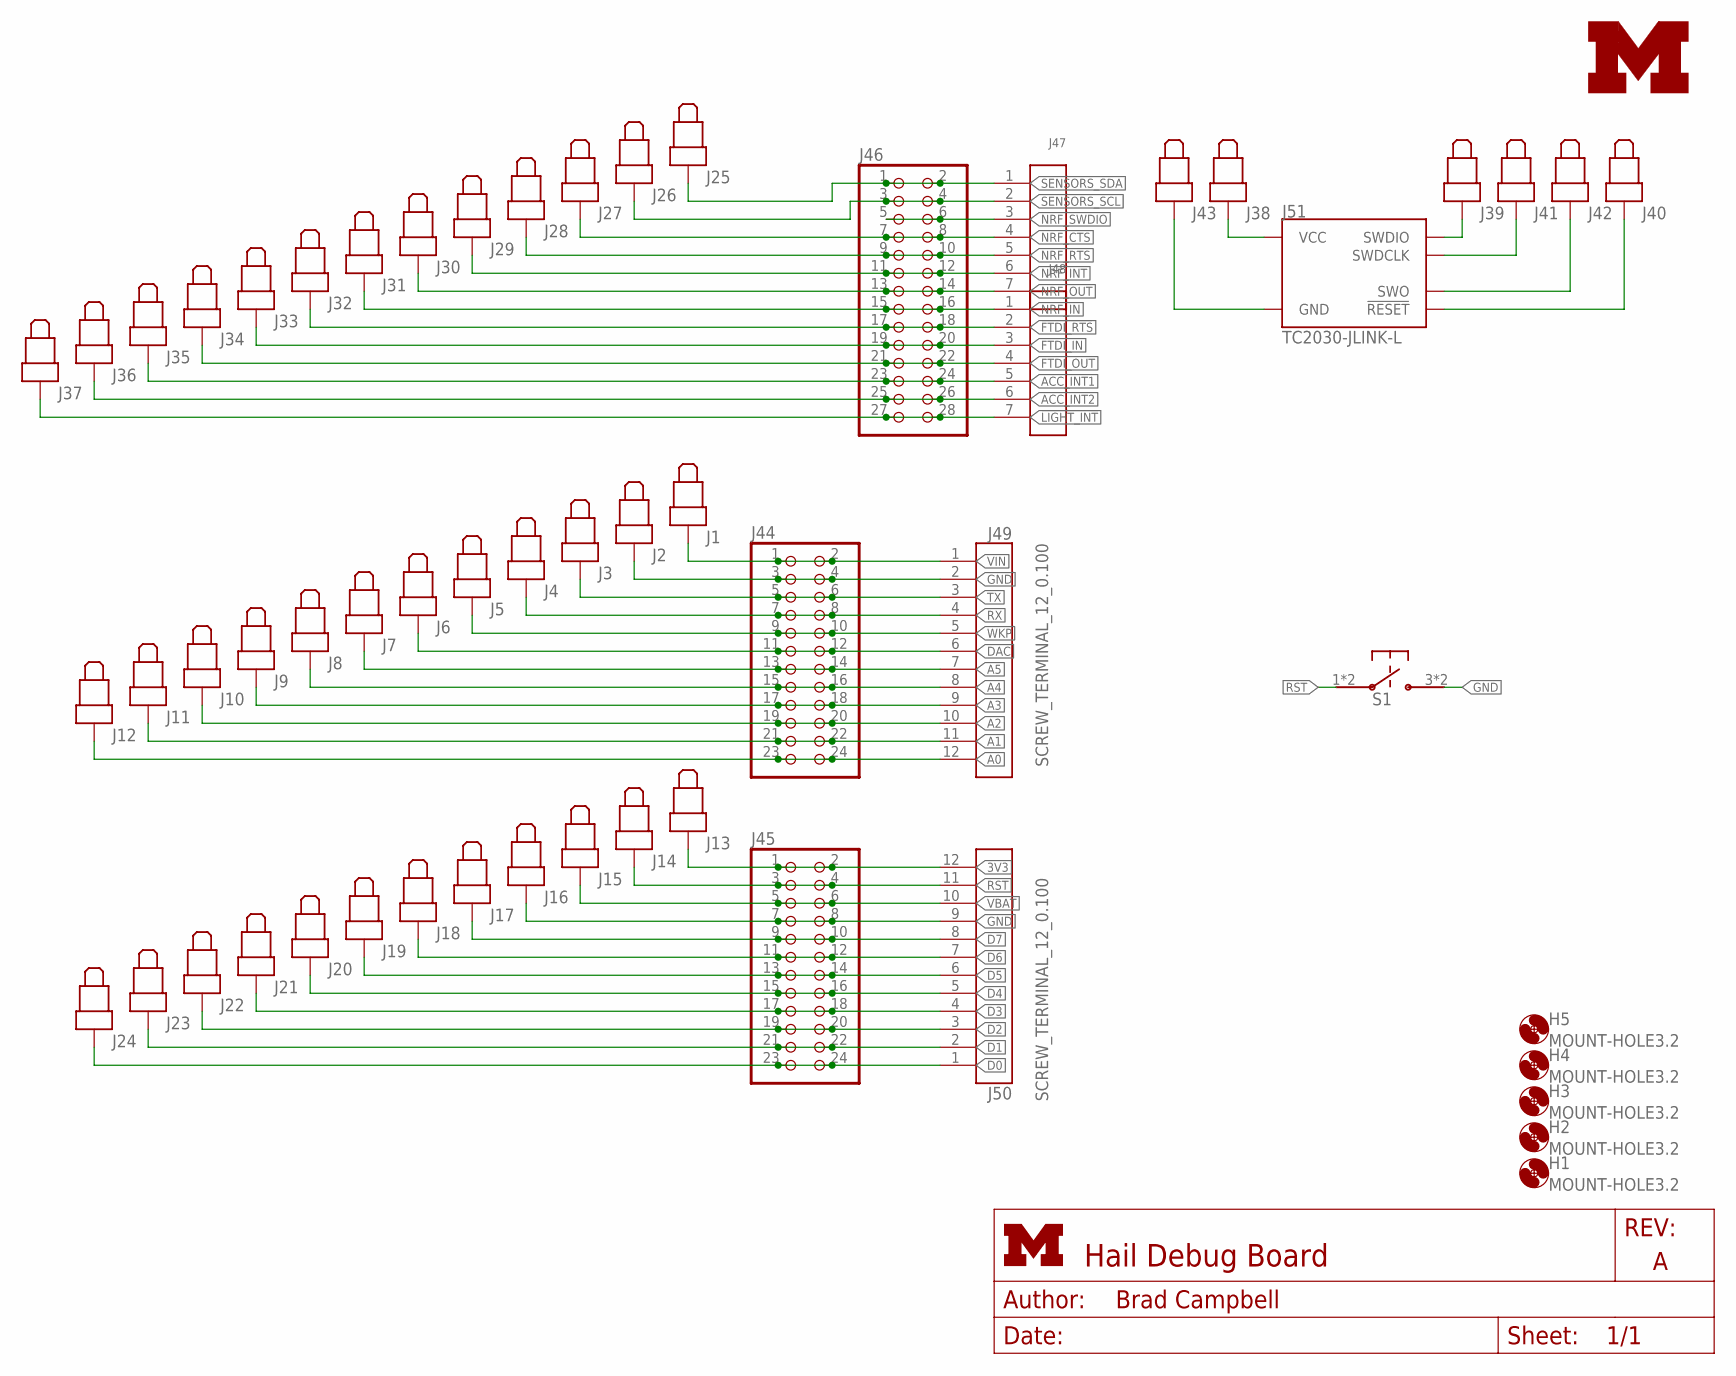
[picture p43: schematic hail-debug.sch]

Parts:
H1, H2, H3, H4, H5: MOUNT-HOLE3.2; 3,2
J1, J2, J3, J4, J5, J6, J7, J8, J9, J10, J11, J12, J13, J14, J15, J16, J17, J18, J19, J20, J21, J22, J23, J24: MILLMAX_0908-X-15-20-75-14-11-0; POGO_0908-X-15-20-75-14-11-0
J25, J26, J27, J28, J29, J30, J31, J32, J33, J34, J35, J36, J37, J38, J39, J40, J41, J42, J43: MILLMAX_0985-X-15-20-71-14-11-0; POGO_0985-X-15-20-71-14-11-0
J44, J45: PINHD-2X12; 2X12; DIGIKEY S2011EC-12-ND
J46: PINHD-2X14; 2X14; DIGIKEY S2011EC-14-ND
J47, J48: SCREW-TERMINAL_7_0.100; CONN_BLOCK_7
J49, J50: SCREW_TERMINAL_12_0.100; CONN_BLOCK_12
J51: TC2030-JLINK-L; TC2030-IDC
LOGO1: UMICH_SOLID_SMALL+; UMICH_SOLID_100MIL
S1: PTS645SM43SMTR92; PTS645

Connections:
3V3: J13.P$1, J45.1, J45.2, J50.12
!FTDI_RTS: J32.P1, J46.17, J46.18, J48.2
!LIGHT_INT: J37.P1, J46.27, J46.28, J48.7
!NRF_RESET: J40.P1, J51.3 (!RESET)
A0: J12.P$1, J44.23, J44.24, J49.12
A1: J11.P$1, J44.21, J44.22, J49.11
A2: J10.P$1, J44.19, J44.20, J49.10
A3: J9.P$1, J44.17, J44.18, J49.9
A4: J8.P$1, J44.15, J44.16, J49.8
A5: J7.P$1, J44.13, J44.14, J49.7
ACC_INT1: J35.P1, J46.23, J46.24, J48.5
ACC_INT2: J36.P1, J46.25, J46.26, J48.6
D0: J24.P$1, J45.23, J45.24, J50.1
D1: J23.P$1, J45.21, J45.22, J50.2
D2: J22.P$1, J45.19, J45.20, J50.3
D3: J21.P$1, J45.17, J45.18, J50.4
D4: J20.P$1, J45.15, J45.16, J50.5
D5: J19.P$1, J45.13, J45.14, J50.6
D6: J18.P$1, J45.11, J45.12, J50.7
D7: J17.P$1, J45.9, J45.10, J50.8
DAC: J6.P$1, J44.11, J44.12, J49.6
FTDI_IN: J33.P1, J46.19, J46.20, J48.3
FTDI_OUT: J34.P1, J46.21, J46.22, J48.4
GND: J2.P$1, J16.P$1, J43.P1, J44.3, J44.4, J45.7, J45.8, J49.2, J50.9, J51.5 (GND), S1.3, S1.4
NRF_CTS: J27.P1, J46.7, J46.8, J47.4
NRF_IN: J31.P1, J46.15, J46.16, J48.1
NRF_INT: J29.P1, J46.11, J46.12, J47.6
NRF_OUT: J30.P1, J46.13, J46.14, J47.7
NRF_RTS: J28.P1, J46.9, J46.10, J47.5
NRF_SWDCLK: J41.P1, J51.4 (SWDCLK)
NRF_SWDIO: J39.P1, J46.5, J46.6, J47.3, J51.2 (SWDIO)
NRF_SWO: J42.P1
NRV_VCC: J38.P1, J51.1 (VCC)
RST: J14.P$1, J45.3, J45.4, J50.11, S1.1, S1.2
RX: J4.P$1, J44.7, J44.8, J49.4
SENSORS_SCL: J26.P1, J46.3, J46.4, J47.2
SENSORS_SDA: J25.P1, J46.1, J46.2, J47.1
TX: J3.P$1, J44.5, J44.6, J49.3
VBAT: J15.P$1, J45.5, J45.6, J50.10
VIN: J1.P$1, J44.1, J44.2, J49.1
WKP: J5.P$1, J44.9, J44.10, J49.5

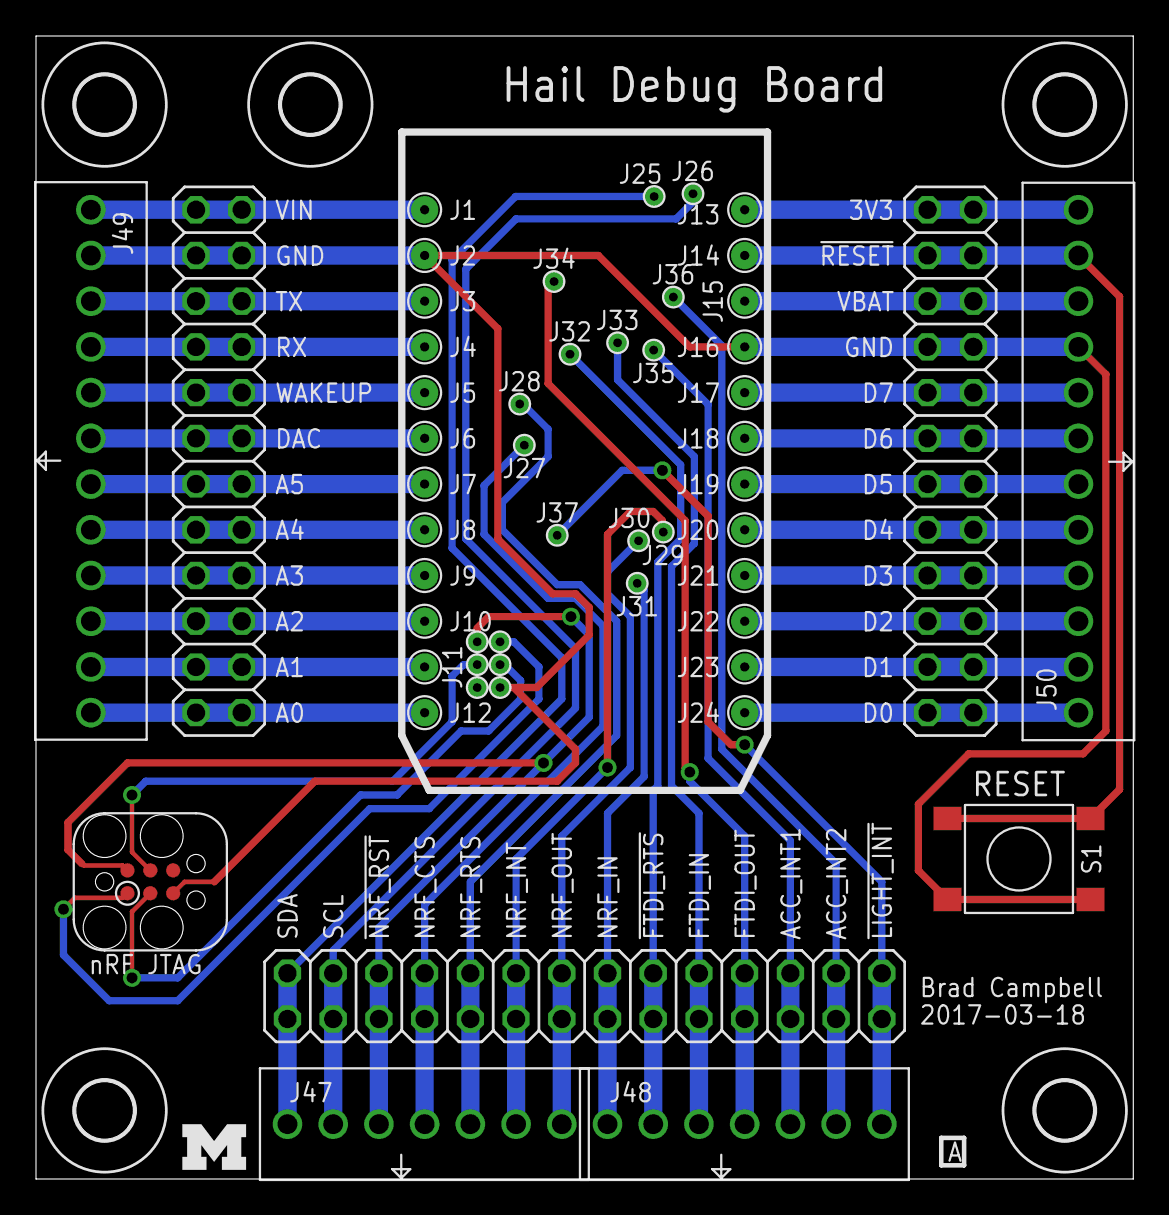
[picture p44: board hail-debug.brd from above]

Board: 2 copper layers, 61.0 x 63.5 mm, 58 parts (0 on the bottom side), 40 nets.

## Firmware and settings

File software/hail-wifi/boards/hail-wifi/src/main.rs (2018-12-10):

//! Board file for Hail+WiFi
//!
//! - <https://github.com/tock/tock/tree/master/boards/hail>
//! - <https://github.com/lab11/hail>

#![no_std]
#![no_main]
#![feature(in_band_lifetimes)]
#![deny(missing_docs)]

extern crate capsules;
#[allow(unused_imports)]
#[macro_use(create_capability, debug, debug_gpio, static_init)]
extern crate kernel;
extern crate cortexm4;
extern crate sam4l;

use capsules::virtual_alarm::{MuxAlarm, VirtualMuxAlarm};
use capsules::virtual_i2c::{I2CDevice, MuxI2C};
use capsules::virtual_spi::{MuxSpiMaster, VirtualSpiMasterDevice};
use capsules::virtual_uart::{UartDevice, UartMux};
use kernel::capabilities;
use kernel::hil;
use kernel::hil::entropy::Entropy32;
use kernel::hil::rng::Rng;
use kernel::hil::spi::SpiMaster;
use kernel::hil::Controller;
use kernel::Platform;

mod at_commands_driver;
mod uart_receive_until_terminator;

/// Support routines for debugging I/O.
///
/// Note: Use of this module will trample any other USART0 configuration.
#[macro_use]
pub mod io;

static mut SPI_READ_BUF: [u8; 64] = [0; 64];
static mut SPI_WRITE_BUF: [u8; 64] = [0; 64];

// State for loading and holding applications.

// Number of concurrent processes this platform supports.
const NUM_PROCS: usize = 20;

// How should the kernel respond when a process faults.
const FAULT_RESPONSE: kernel::procs::FaultResponse = kernel::procs::FaultResponse::Panic;

// RAM to be shared by all application processes.
#[link_section = ".app_memory"]
static mut APP_MEMORY: [u8; 49152] = [0; 49152];

// Actual memory for holding the active process structures.
static mut PROCESSES: [Option<&'static kernel::procs::ProcessType>; NUM_PROCS] = [None; NUM_PROCS];

/// Dummy buffer that causes the linker to reserve enough space for the stack.
#[no_mangle]
#[link_section = ".stack_buffer"]
pub static mut STACK_MEMORY: [u8; 0x1000] = [0; 0x1000];

/// A structure representing this platform that holds references to all
/// capsules for this platform.
struct Hail {
    console: &'static capsules::console::Console<'static, UartDevice<'static>>,
    gpio: &'static capsules::gpio::GPIO<'static, sam4l::gpio::GPIOPin>,
    alarm: &'static capsules::alarm::AlarmDriver<
        'static,
        VirtualMuxAlarm<'static, sam4l::ast::Ast<'static>>,
    >,
    ambient_light: &'static capsules::ambient_light::AmbientLight<'static>,
    temp: &'static capsules::temperature::TemperatureSensor<'static>,
    ninedof: &'static capsules::ninedof::NineDof<'static>,
    humidity: &'static capsules::humidity::HumiditySensor<'static>,
    spi: &'static capsules::spi::Spi<'static, VirtualSpiMasterDevice<'static, sam4l::spi::SpiHw>>,
    nrf51822: &'static capsules::nrf51822_serialization::Nrf51822Serialization<
        'static,
        sam4l::usart::USART,
    >,
    adc: &'static capsules::adc::Adc<'static, sam4l::adc::Adc>,
    led: &'static capsules::led::LED<'static, sam4l::gpio::GPIOPin>,
    button: &'static capsules::button::Button<'static, sam4l::gpio::GPIOPin>,
    rng: &'static capsules::rng::RngDriver<'static>,
    ipc: kernel::ipc::IPC,
    crc: &'static capsules::crc::Crc<'static, sam4l::crccu::Crccu<'static>>,
    dac: &'static capsules::dac::Dac<'static>,
    // at: &'static at_commands_driver::AtCommands<'static,
    // uart_receive_until_terminator::UartTerminatorReceiver<'static, sam4l::usart::USART>>,
    at: &'static at_commands_driver::AtCommands<'static, sam4l::usart::USART>,
}

/// Mapping of integer syscalls to objects that implement syscalls.
impl Platform for Hail {
    fn with_driver<F, R>(&self, driver_num: usize, f: F) -> R
    where
        F: FnOnce(Option<&kernel::Driver>) -> R,
    {
        match driver_num {
            capsules::console::DRIVER_NUM => f(Some(self.console)),
            capsules::gpio::DRIVER_NUM => f(Some(self.gpio)),

            capsules::alarm::DRIVER_NUM => f(Some(self.alarm)),
            capsules::spi::DRIVER_NUM => f(Some(self.spi)),
            capsules::nrf51822_serialization::DRIVER_NUM => f(Some(self.nrf51822)),
            capsules::ambient_light::DRIVER_NUM => f(Some(self.ambient_light)),
            capsules::adc::DRIVER_NUM => f(Some(self.adc)),
            capsules::led::DRIVER_NUM => f(Some(self.led)),
            capsules::button::DRIVER_NUM => f(Some(self.button)),
            capsules::humidity::DRIVER_NUM => f(Some(self.humidity)),
            capsules::temperature::DRIVER_NUM => f(Some(self.temp)),
            capsules::ninedof::DRIVER_NUM => f(Some(self.ninedof)),

            capsules::rng::DRIVER_NUM => f(Some(self.rng)),

            capsules::crc::DRIVER_NUM => f(Some(self.crc)),

            capsules::dac::DRIVER_NUM => f(Some(self.dac)),
            at_commands_driver::DRIVER_NUM => f(Some(self.at)),

            kernel::ipc::DRIVER_NUM => f(Some(&self.ipc)),
            _ => f(None),
        }
    }
}

/// Helper function called during bring-up that configures multiplexed I/O.
unsafe fn set_pin_primary_functions() {
    use sam4l::gpio::PeripheralFunction::{A, B};
    use sam4l::gpio::{PA, PB};

    PA[04].configure(Some(A)); // A0 - ADC0
    PA[05].configure(Some(A)); // A1 - ADC1
                               // DAC/WKP mode
    PA[06].configure(Some(A)); // DAC
    PA[07].configure(None); //... WKP - Wakeup
                            // // Analog Comparator Mode
                            // PA[06].configure(Some(E)); // ACAN0 - ACIFC
                            // PA[07].configure(Some(E)); // ACAP0 - ACIFC
    PA[08].configure(Some(A)); // FTDI_RTS - USART0 RTS
    PA[09].configure(None); //... ACC_INT1 - FXOS8700CQ Interrupt 1
    PA[10].configure(None); //... unused
    PA[11].configure(Some(A)); // FTDI_OUT - USART0 RX FTDI->SAM4L
    PA[12].configure(Some(A)); // FTDI_IN - USART0 TX SAM4L->FTDI
    PA[13].configure(None); //... RED_LED
    PA[14].configure(None); //... BLUE_LED
    PA[15].configure(None); //... GREEN_LED
    PA[16].configure(None); //... BUTTON - User Button
    PA[17].configure(None); //... !NRF_RESET - Reset line for nRF51822
    PA[18].configure(None); //... ACC_INT2 - FXOS8700CQ Interrupt 2
    PA[19].configure(None); //... unused
    PA[20].configure(None); //... !LIGHT_INT - ISL29035 Light Sensor Interrupt
                            // SPI Mode
    PA[21].configure(Some(A)); // D3 - SPI MISO
    PA[22].configure(Some(A)); // D2 - SPI MOSI
    PA[23].configure(Some(A)); // D4 - SPI SCK
    PA[24].configure(Some(A)); // D5 - SPI CS0
                               // // I2C Mode
                               // PA[21].configure(None); // D3
                               // PA[22].configure(None); // D2
                               // PA[23].configure(Some(B)); // D4 - TWIMS0 SDA
                               // PA[24].configure(Some(B)); // D5 - TWIMS0 SCL
                               // UART Mode
    PA[25].configure(Some(B)); // RX - USART2 RXD
    PA[26].configure(Some(B)); // TX - USART2 TXD

    PB[00].configure(Some(A)); // SENSORS_SDA - TWIMS1 SDA
    PB[01].configure(Some(A)); // SENSORS_SCL - TWIMS1 SCL
                               // ADC Mode
    PB[02].configure(Some(A)); // A2 - ADC3
    PB[03].configure(Some(A)); // A3 - ADC4
                               // // Analog Comparator Mode
                               // PB[02].configure(Some(E)); // ACBN0 - ACIFC
                               // PB[03].configure(Some(E)); // ACBP0 - ACIFC
    PB[04].configure(Some(A)); // A4 - ADC5
    PB[05].configure(Some(A)); // A5 - ADC6
    PB[06].configure(Some(A)); // NRF_CTS - USART3 RTS
    PB[07].configure(Some(A)); // NRF_RTS - USART3 CTS
    PB[08].configure(None); //... NRF_INT - Interrupt line nRF->SAM4L
    PB[09].configure(Some(A)); // NRF_OUT - USART3 RXD
    PB[10].configure(Some(A)); // NRF_IN - USART3 TXD
    PB[11].configure(None); //... D6
    PB[12].configure(None); //... D7
    PB[13].configure(None); //... unused
    PB[14].configure(None); //... D0
    PB[15].configure(None); //... D1
}

/// Reset Handler.
///
/// This symbol is loaded into vector table by the SAM4L chip crate.
/// When the chip first powers on or later does a hard reset, after the core
/// initializes all the hardware, the address of this function is loaded and
/// execution begins here.
#[no_mangle]
pub unsafe fn reset_handler() {
    sam4l::init();

    sam4l::pm::PM.setup_system_clock(sam4l::pm::SystemClockSource::PllExternalOscillatorAt48MHz {
        frequency: sam4l::pm::OscillatorFrequency::Frequency16MHz,
        startup_mode: sam4l::pm::OscillatorStartup::SlowStart,
    });

    // Source 32Khz and 1Khz clocks from RC23K (SAM4L Datasheet 11.6.8)
    sam4l::bpm::set_ck32source(sam4l::bpm::CK32Source::RC32K);

    set_pin_primary_functions();

    let board_kernel = static_init!(kernel::Kernel, kernel::Kernel::new(&PROCESSES));

    // Create capabilities that the board needs to call certain protected kernel
    // functions.
    let process_management_capability =
        create_capability!(capabilities::ProcessManagementCapability);
    let main_loop_capability = create_capability!(capabilities::MainLoopCapability);
    let memory_allocation_capability = create_capability!(capabilities::MemoryAllocationCapability);

    // Configure kernel debug gpios as early as possible
    kernel::debug::assign_gpios(
        Some(&sam4l::gpio::PA[13]),
        Some(&sam4l::gpio::PA[15]),
        Some(&sam4l::gpio::PA[14]),
    );

    let chip = static_init!(sam4l::chip::Sam4l, sam4l::chip::Sam4l::new());

    // Initialize USART0 for Uart
    sam4l::usart::USART0.set_mode(sam4l::usart::UsartMode::Uart);

    // Create a shared UART channel for the console and for kernel debug.
    let uart_mux = static_init!(
        UartMux<'static>,
        UartMux::new(
            &sam4l::usart::USART0,
            &mut capsules::virtual_uart::RX_BUF,
            115200
        )
    );
    hil::uart::UART::set_client(&sam4l::usart::USART0, uart_mux);

    // Create a UartDevice for the console.
    let console_uart = static_init!(UartDevice, UartDevice::new(uart_mux, true));
    console_uart.setup();
    let console = static_init!(
        capsules::console::Console<UartDevice>,
        capsules::console::Console::new(
            console_uart,
            115200,
            &mut capsules::console::WRITE_BUF,
            &mut capsules::console::READ_BUF,
            board_kernel.create_grant(&memory_allocation_capability)
        )
    );
    hil::uart::UART::set_client(console_uart, console);

    // Setup the process inspection console
    let process_console_uart = static_init!(UartDevice, UartDevice::new(uart_mux, true));
    process_console_uart.setup();
    pub struct ProcessConsoleCapability;
    unsafe impl capabilities::ProcessManagementCapability for ProcessConsoleCapability {}
    let process_console = static_init!(
        capsules::process_console::ProcessConsole<UartDevice, ProcessConsoleCapability>,
        capsules::process_console::ProcessConsole::new(
            process_console_uart,
            115200,
            &mut capsules::process_console::WRITE_BUF,
            &mut capsules::process_console::READ_BUF,
            &mut capsules::process_console::COMMAND_BUF,
            board_kernel,
            ProcessConsoleCapability,
        )
    );
    hil::uart::UART::set_client(process_console_uart, process_console);
    process_console.initialize();

    // Initialize USART3 for Uart
    sam4l::usart::USART3.set_mode(sam4l::usart::UsartMode::Uart);
    // Create the Nrf51822Serialization driver for passing BLE commands
    // over UART to the nRF51822 radio.
    let nrf_serialization = static_init!(
        capsules::nrf51822_serialization::Nrf51822Serialization<sam4l::usart::USART>,
        capsules::nrf51822_serialization::Nrf51822Serialization::new(
            &sam4l::usart::USART3,
            &sam4l::gpio::PA[17],
            &mut capsules::nrf51822_serialization::WRITE_BUF,
            &mut capsules::nrf51822_serialization::READ_BUF
        )
    );
    hil::uart::UART::set_client(&sam4l::usart::USART3, nrf_serialization);

    let ast = &sam4l::ast::AST;

    let mux_alarm = static_init!(
        MuxAlarm<'static, sam4l::ast::Ast>,
        MuxAlarm::new(&sam4l::ast::AST)
    );
    ast.configure(mux_alarm);

    let sensors_i2c = static_init!(MuxI2C<'static>, MuxI2C::new(&sam4l::i2c::I2C1));
    sam4l::i2c::I2C1.set_master_client(sensors_i2c);

    // SI7021 Temperature / Humidity Sensor, address: 0x40
    let si7021_i2c = static_init!(
        capsules::virtual_i2c::I2CDevice,
        capsules::virtual_i2c::I2CDevice::new(sensors_i2c, 0x40)
    );
    let si7021_virtual_alarm = static_init!(
        VirtualMuxAlarm<'static, sam4l::ast::Ast>,
        VirtualMuxAlarm::new(mux_alarm)
    );
    let si7021 = static_init!(
        capsules::si7021::SI7021<'static, VirtualMuxAlarm<'static, sam4l::ast::Ast>>,
        capsules::si7021::SI7021::new(
            si7021_i2c,
            si7021_virtual_alarm,
            &mut capsules::si7021::BUFFER
        )
    );
    si7021_i2c.set_client(si7021);
    si7021_virtual_alarm.set_client(si7021);

    let temp = static_init!(
        capsules::temperature::TemperatureSensor<'static>,
        capsules::temperature::TemperatureSensor::new(
            si7021,
            board_kernel.create_grant(&memory_allocation_capability)
        )
    );
    kernel::hil::sensors::TemperatureDriver::set_client(si7021, temp);

    let humidity = static_init!(
        capsules::humidity::HumiditySensor<'static>,
        capsules::humidity::HumiditySensor::new(
            si7021,
            board_kernel.create_grant(&memory_allocation_capability)
        )
    );
    kernel::hil::sensors::HumidityDriver::set_client(si7021, humidity);

    // Configure the ISL29035, device address 0x44
    let isl29035_i2c = static_init!(I2CDevice, I2CDevice::new(sensors_i2c, 0x44));
    let isl29035_virtual_alarm = static_init!(
        VirtualMuxAlarm<'static, sam4l::ast::Ast>,
        VirtualMuxAlarm::new(mux_alarm)
    );
    let isl29035 = static_init!(
        capsules::isl29035::Isl29035<'static, VirtualMuxAlarm<'static, sam4l::ast::Ast>>,
        capsules::isl29035::Isl29035::new(
            isl29035_i2c,
            isl29035_virtual_alarm,
            &mut capsules::isl29035::BUF
        )
    );
    isl29035_i2c.set_client(isl29035);
    isl29035_virtual_alarm.set_client(isl29035);

    let ambient_light = static_init!(
        capsules::ambient_light::AmbientLight<'static>,
        capsules::ambient_light::AmbientLight::new(
            isl29035,
            board_kernel.create_grant(&memory_allocation_capability)
        )
    );
    hil::sensors::AmbientLight::set_client(isl29035, ambient_light);

    // Alarm
    let virtual_alarm1 = static_init!(
        VirtualMuxAlarm<'static, sam4l::ast::Ast>,
        VirtualMuxAlarm::new(mux_alarm)
    );
    let alarm = static_init!(
        capsules::alarm::AlarmDriver<'static, VirtualMuxAlarm<'static, sam4l::ast::Ast>>,
        capsules::alarm::AlarmDriver::new(
            virtual_alarm1,
            board_kernel.create_grant(&memory_allocation_capability)
        )
    );
    virtual_alarm1.set_client(alarm);

    // FXOS8700CQ accelerometer, device address 0x1e
    let fxos8700_i2c = static_init!(I2CDevice, I2CDevice::new(sensors_i2c, 0x1e));
    let fxos8700 = static_init!(
        capsules::fxos8700cq::Fxos8700cq<'static>,
        capsules::fxos8700cq::Fxos8700cq::new(
            fxos8700_i2c,
            &sam4l::gpio::PA[9],
            &mut capsules::fxos8700cq::BUF
        )
    );
    fxos8700_i2c.set_client(fxos8700);
    sam4l::gpio::PA[9].set_client(fxos8700);

    let ninedof = static_init!(
        capsules::ninedof::NineDof<'static>,
        capsules::ninedof::NineDof::new(
            fxos8700,
            board_kernel.create_grant(&memory_allocation_capability)
        )
    );
    hil::sensors::NineDof::set_client(fxos8700, ninedof);

    // Initialize and enable SPI HAL
    // Set up an SPI MUX, so there can be multiple clients
    let mux_spi = static_init!(
        MuxSpiMaster<'static, sam4l::spi::SpiHw>,
        MuxSpiMaster::new(&sam4l::spi::SPI)
    );

    sam4l::spi::SPI.set_client(mux_spi);
    sam4l::spi::SPI.init();

    // Create a virtualized client for SPI system call interface
    // CS line is CS0
    let syscall_spi_device = static_init!(
        VirtualSpiMasterDevice<'static, sam4l::spi::SpiHw>,
        VirtualSpiMasterDevice::new(mux_spi, 0)
    );

    // Create the SPI system call capsule, passing the client
    let spi_syscalls = static_init!(
        capsules::spi::Spi<'static, VirtualSpiMasterDevice<'static, sam4l::spi::SpiHw>>,
        capsules::spi::Spi::new(syscall_spi_device)
    );

    spi_syscalls.config_buffers(&mut SPI_READ_BUF, &mut SPI_WRITE_BUF);
    syscall_spi_device.set_client(spi_syscalls);

    // LEDs
    let led_pins = static_init!(
        [(&'static sam4l::gpio::GPIOPin, capsules::led::ActivationMode); 3],
        [
            (
                &sam4l::gpio::PA[13],
                capsules::led::ActivationMode::ActiveLow
            ), // Red
            (
                &sam4l::gpio::PA[15],
                capsules::led::ActivationMode::ActiveLow
            ), // Green
            (
                &sam4l::gpio::PA[14],
                capsules::led::ActivationMode::ActiveLow
            ),
        ]
    ); // Blue
    let led = static_init!(
        capsules::led::LED<'static, sam4l::gpio::GPIOPin>,
        capsules::led::LED::new(led_pins)
    );

    // BUTTONs
    let button_pins = static_init!(
        [(&'static sam4l::gpio::GPIOPin, capsules::button::GpioMode); 1],
        [(
            &sam4l::gpio::PA[16],
            capsules::button::GpioMode::LowWhenPressed
        )]
    );
    let button = static_init!(
        capsules::button::Button<'static, sam4l::gpio::GPIOPin>,
        capsules::button::Button::new(
            button_pins,
            board_kernel.create_grant(&memory_allocation_capability)
        )
    );
    for &(btn, _) in button_pins.iter() {
        btn.set_client(button);
    }

    // Setup ADC
    let adc_channels = static_init!(
        [&'static sam4l::adc::AdcChannel; 6],
        [
            &sam4l::adc::CHANNEL_AD0, // A0
            &sam4l::adc::CHANNEL_AD1, // A1
            &sam4l::adc::CHANNEL_AD3, // A2
            &sam4l::adc::CHANNEL_AD4, // A3
            &sam4l::adc::CHANNEL_AD5, // A4
            &sam4l::adc::CHANNEL_AD6, // A5
        ]
    );
    let adc = static_init!(
        capsules::adc::Adc<'static, sam4l::adc::Adc>,
        capsules::adc::Adc::new(
            &mut sam4l::adc::ADC0,
            adc_channels,
            &mut capsules::adc::ADC_BUFFER1,
            &mut capsules::adc::ADC_BUFFER2,
            &mut capsules::adc::ADC_BUFFER3
        )
    );
    sam4l::adc::ADC0.set_client(adc);

    // Setup RNG
    let entropy_to_random = static_init!(
        capsules::rng::Entropy32ToRandom<'static>,
        capsules::rng::Entropy32ToRandom::new(&sam4l::trng::TRNG)
    );
    let rng = static_init!(
        capsules::rng::RngDriver<'static>,
        capsules::rng::RngDriver::new(
            entropy_to_random,
            board_kernel.create_grant(&memory_allocation_capability)
        )
    );
    sam4l::trng::TRNG.set_client(entropy_to_random);
    entropy_to_random.set_client(rng);

    // set GPIO driver controlling remaining GPIO pins
    let gpio_pins = static_init!(
        [&'static sam4l::gpio::GPIOPin; 4],
        [
            &sam4l::gpio::PB[14], // D0
            &sam4l::gpio::PB[15], // D1
            &sam4l::gpio::PB[11], // D6
            &sam4l::gpio::PB[12],
        ]
    ); // D7
    let gpio = static_init!(
        capsules::gpio::GPIO<'static, sam4l::gpio::GPIOPin>,
        capsules::gpio::GPIO::new(gpio_pins)
    );
    for pin in gpio_pins.iter() {
        pin.set_client(gpio);
    }

    // CRC
    let crc = static_init!(
        capsules::crc::Crc<'static, sam4l::crccu::Crccu<'static>>,
        capsules::crc::Crc::new(
            &mut sam4l::crccu::CRCCU,
            board_kernel.create_grant(&memory_allocation_capability)
        )
    );
    sam4l::crccu::CRCCU.set_client(crc);

    // DAC
    let dac = static_init!(
        capsules::dac::Dac<'static>,
        capsules::dac::Dac::new(&mut sam4l::dac::DAC)
    );

    //
    // UART for AT commands to Wi-Fi radio
    //

    // First, put the correct USART that is connected to the external
    // pins on the Hail board (and then to the Wi-Fi shield) in UART mode.
    sam4l::usart::USART2.set_mode(sam4l::usart::UsartMode::Uart);

    // Now we need to add a layer that implements the receive until
    // terminator functionality. This is needed for the AT commands which
    // can return an arbitrary amount of data until a terminator command
    // is received.
    // let uart_recv_terminator = static_init!(
    //     uart_receive_until_terminator::UartTerminatorReceiver<'static, sam4l::usart::USART>,
    //     uart_receive_until_terminator::UartTerminatorReceiver::new(
    //         &sam4l::usart::USART2)
    //     );
    // hil::uart::UART::set_client(&sam4l::usart::USART2, uart_recv_terminator);

    // Next we create the AT command driver that the userland app will use.
    let at_driver = static_init!(
        // at_commands_driver::AtCommands<'static, uart_receive_until_terminator::UartTerminatorReceiver<'static, sam4l::usart::USART>>,
        at_commands_driver::AtCommands<'static, sam4l::usart::USART>,
        at_commands_driver::AtCommands::new(
            &sam4l::usart::USART2,
            &mut at_commands_driver::TX_BUF,
            &mut at_commands_driver::RX_BUF,
            board_kernel.create_grant(&memory_allocation_capability)
        )
    );
    hil::uart::UART::set_client(&sam4l::usart::USART2, at_driver);
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

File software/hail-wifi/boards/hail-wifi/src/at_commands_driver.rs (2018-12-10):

//! Userspace driver for AT commands.

// use uart_receive_until_terminator::UartReceiveUntilTerminator;

use kernel::common::cells::{OptionalCell, TakeCell};
use kernel::hil;
use kernel::hil::uart::UARTReceiveAdvanced;
use kernel::{AppId, AppSlice, Callback, Driver, Grant, ReturnCode, Shared};

/// Syscall driver number.
pub const DRIVER_NUM: usize = 0xffff0001;

#[derive(Default)]
pub struct App {
    tx_callback: Option<Callback>,
    tx_buffer: Option<AppSlice<Shared, u8>>,
    rx_callback: Option<Callback>,
    rx_buffer: Option<AppSlice<Shared, u8>>,
}

pub static mut TX_BUF: [u8; 3000] = [0; 3000];
pub static mut RX_BUF: [u8; 3000] = [0; 3000];

pub struct AtCommands<'a, U: UARTReceiveAdvanced> {
    uart: &'a U,
    apps: Grant<App>,
    tx_in_progress: OptionalCell<AppId>,
    tx_buffer: TakeCell<'static, [u8]>,
    rx_in_progress: OptionalCell<AppId>,
    rx_buffer: TakeCell<'static, [u8]>,
}

impl<U: UARTReceiveAdvanced> AtCommands<'a, U> {
    pub fn new(
        uart: &'a U,
        tx_buffer: &'static mut [u8],
        rx_buffer: &'static mut [u8],
        grant: Grant<App>,
    ) -> AtCommands<'a, U> {
        AtCommands {
            uart: uart,
            apps: grant,
            tx_in_progress: OptionalCell::empty(),
            tx_buffer: TakeCell::new(tx_buffer),
            rx_in_progress: OptionalCell::empty(),
            rx_buffer: TakeCell::new(rx_buffer),
        }
    }

    pub fn initialize(&self, params: hil::uart::UARTParameters) {
        self.uart.configure(params);
    }
}

impl<U: UARTReceiveAdvanced> Driver for AtCommands<'a, U> {
    /// Setup shared buffers.
    ///
    /// ### `allow_num`
    ///
    /// - `1`: Share a TX buffer for sending AT commands to the radio.
    /// - `2`: Share a RX buffer for receiving data from the radio.
    fn allow(
        &self,
        appid: AppId,
        allow_num: usize,
        slice: Option<AppSlice<Shared, u8>>,
    ) -> ReturnCode {
        match allow_num {
            1 => self
                .apps
                .enter(appid, |app, _| {
                    app.tx_buffer = slice;
                    ReturnCode::SUCCESS
                }).unwrap_or_else(|err| err.into()),
            2 => self
                .apps
                .enter(appid, |app, _| {
                    app.rx_buffer = slice;
                    ReturnCode::SUCCESS
                }).unwrap_or_else(|err| err.into()),
            _ => ReturnCode::ENOSUPPORT,
        }
    }

    /// Setup callbacks.
    ///
    /// ### `subscribe_num`
    ///
    /// - `1`: Finished sending AT command.
    /// - `2`: Received data from the radio.
    fn subscribe(
        &self,
        subscribe_num: usize,
        callback: Option<Callback>,
        app_id: AppId,
    ) -> ReturnCode {
        match subscribe_num {
            1 => self
                .apps
                .enter(app_id, |app, _| {
                    app.tx_callback = callback;
                    ReturnCode::SUCCESS
                }).unwrap_or_else(|err| err.into()),
            2 => self
                .apps
                .enter(app_id, |app, _| {
                    app.rx_callback = callback;
                    ReturnCode::SUCCESS
                }).unwrap_or_else(|err| err.into()),
            _ => ReturnCode::ENOSUPPORT,
        }
    }

    /// Initiate AT commands and other interactions with the radio.
    ///
    /// ### `command_num`
    ///
    /// - `0`: Driver check.
    /// - `1`: Transmits a buffer passed via `allow`, up to the length
    ///        passed in `arg1`.
    /// - `2`: Receives into a buffer passed via `allow`, waiting for a `\n`.
    fn command(&self, cmd_num: usize, arg1: usize, _: usize, appid: AppId) -> ReturnCode {
        match cmd_num {
            0 /* check if present */ => ReturnCode::SUCCESS,
            1 => {
                let len = arg1;
// debug!("tx");
                self.apps.enter(appid, |app, _| {
                    app.tx_buffer.as_ref().map_or(ReturnCode::ENOMEM, |slice| {
                        // Check that we aren't trying to send more than the
                        // shared AppSlice.
                        if len > slice.len() {
                            ReturnCode::EINVAL
                        } else {
                            // Copy into our buffer and then TX.
                            self.tx_buffer.take().map(|buffer| {
                                for (i, c) in slice.as_ref()[0..len]
                                    .iter()
                                    .enumerate()
                                {
                                    if buffer.len() <= i {
                                        break;
                                    }
                                    buffer[i] = *c;
                                }
// debug!("tx");
// if (len == 15) {
// debug_gpio!(0, toggle);
// }
                                self.tx_in_progress.set(appid);
                                self.uart.transmit(buffer, len);
                            });
                            ReturnCode::SUCCESS
                        }
                    })
                }).unwrap_or_else(|err| err.into())
            }
            2 => {
                // debug!("recv");
                self.rx_buffer.take().map_or(ReturnCode::ENOMEM, |buffer| {
                    self.rx_in_progress.set(appid);
                    // debug!("yess");
                    // self.uart.receive_until_terminator(buffer, '\n' as u8);
                    self.uart.receive_automatic(buffer, 100);
                    ReturnCode::SUCCESS
                })
            }
            _ => ReturnCode::ENOSUPPORT
        }
    }
}
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

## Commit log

2016-12-03 Renamed to Hail. Added BOM
    [hail.brd, hail.sch, hail_bom.csv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]
2016-12-03 Last silkscreen modification
    [hail.brd]
2016-12-03 Panelization of hail
    [merge.cfg]
2016-12-03 Updates from Brad
    [hail.brd]
2016-12-05 Fix bom for github, maybe?
    [hail_bom.csv]
2016-12-05 Update mistaken digikey part numbers
    [hail.brd, hail.sch, hail_bom.csv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]
2016-12-05 Fix autogenerated boms
    [hail_bom.csv]
2016-12-05 Last changes to hail_bom
    [hail_bom.xlsx]
2016-12-16 Update to BOM
    [hail_bom.xlsx]
2016-12-16 Moving hail board to new repo
    [hail.brd, hail.sch, hail_bom.csv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]
2016-12-16 Move to hardware directory
    [hail.brd, hail.sch, hail_bom.csv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]
2016-12-17 Reconfigure hardware folder
    In the future there could be addtional hail hardware
    [hail.brd, hail.sch, hail_bom.csv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]
2016-12-17 Remove debug led blinking
2016-12-17 Fix mistaken pin names and BOM parts
    Pins:
    * fix RGB led pins
    * correct mapping of NRF_RTS/CTS pins
    BOM:
    * FB1 was 0603 by mistake. Picked 0402 package
    * Found part for 12-pin headers for Hail
    [hail.brd, hail.sch, hail_bom.csv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]
2016-12-17 Updated PDF to match changes in schematic
2016-12-19 disable LEDs on serialization
2016-12-19 Started on a revision B
    [hail.brd, hail.sch, hail_bom.csv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]
2017-03-04 update bom with prices
    [hail_bom.xlsx]
2017-03-13 creating breakoutboard
    [hail-debug.brd, hail-debug.sch]
2017-03-13 small fixes
    [hail-debug.brd, hail-debug.sch]
2017-03-13 updates to debug board
    [hail-debug.brd, hail-debug.sch]
2017-03-13 Hail rev B!
    [hail.brd, hail.sch]
2017-03-13 Hail revB production files
    [hail_bom.csv, hail_bom.xlsx]
2017-03-14 add 3d parts
    [hail-debug.SLDASM, hail.SLDASM, holder_bracket.SLDPRT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]
2017-03-17 update layout for MacroFab Standard 4 Layer DRU
    [hail.brd]
2017-03-18 add mpn
    still more to be done here. if you add mpn for house parts you don't get
    the house parts. macrofab is frustratingly difficult to set up. arg.
    [hail.brd, hail.sch]
2017-03-18 finally got the attributes right
    [hail.brd, hail.sch]
2017-03-18 clean up bom a bit
    [hail_bom.xlsx]
2017-03-19 ready to ship hail-debug
    [hail-debug.brd, hail-debug_bom.xlsx]
2017-03-20 Minor trace tweaks. Bump up size of RF trace
    [hail.brd]
2017-03-21 update 3d parts
    [hail-debug.SLDASM, holder_bracket.SLDPRT]
2017-04-24 updated 3d parts for debug board
    [hail-debug.SLDASM, holder_bracket_long.SLDPRT, holder_bracket_post.SLDPRT]
2017-04-26 sigh.. GN -> GND
2017-09-26 Revision C of Hail
    Closes #1
    [hail.brd, hail.sch, hail_bom.csv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]
2017-09-26 Build files for rev c
    [hail_bom.csv]
2017-10-25 Update labels for our new printer
2018-08-08 first pass on hail-wifi board
    [hail-wifi.brd, hail-wifi.sch]
2018-12-02 some updates to hail-wifi
    Rev a doesn't work (wrong esp chip), but I hacked a version which I hope
    will work and then I will make a rev b.
    [hail-wifi.brd, hail-wifi.sch]
2018-12-02 add tock board for hail-wifi
2018-12-10 checkpoint
    actually do have esp32 connecting to wifi and doing http requests

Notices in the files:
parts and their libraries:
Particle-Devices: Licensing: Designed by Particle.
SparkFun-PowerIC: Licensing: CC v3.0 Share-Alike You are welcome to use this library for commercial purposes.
